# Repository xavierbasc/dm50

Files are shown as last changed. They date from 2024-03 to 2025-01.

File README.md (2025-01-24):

# DM50 calculator

The main features of the calculator are the following:

 - 32bit ARM Cortex-M33 MCU ultra low power.
 - Mathematical coprocessor acceleration.
 - Floating Point Unit (FPU).
 - 2MB RAM (STM32U595RJ).
 - 4MB FLASH memory (STM32U595RJ).
 - 16MB FLASH storage Octo-SPI (accessible via USB).
 - USBC port, connects as USB mass storage device.
 - Serial port for communications with external devices.
 - MicroSD memory slot.
 - Integrated speaker and stereo audio output (jack 3.5).
 - Graphic LCD Display (128x64 dots).
 - ESD protection of USBC.
 - LiPO 3.7V rechargeable battery, with JST PH2.0 connector.
 - Possibility of using AAA batteries.
 - Battery charge level sensor.
 - USB power and battery charging status LED indicators.
 - JTAG debug port.
 - Temperature sensor.
 - Same number of keys as the legendary HP48.

# Hardware
Below is a list of the most relevant electronic components:

1. Processor: STM32U5 ARM Cortex-M33 ultra low power with FPU.
2. Display: EA_DOGL128L-6 STN reflective display 128x64.
3. Flash memory: W25Q128JVSIQ 16MB Flash.
4. Voltage regulator: ADP2108 Vin 2.3 - 5.5, Vout 3.3.
5. USB protection: USBLC6-2 ESD protection of VBUS.
6. Battery charger: MCP73831 Lithium-Ion/Lithium-Polymer Battery Charger.

Some of the supported batteries are as follows:

| Batteries | Capacity (mha) |
| --- | :---: |
| AAA Alkaline | 900 - 1155 |
| AAA Ni-MH | 800 - 1000 |
| LiPO 402025 (4.0x20x25) | 150 |
| LiPO LP272247 (2.7x22x47) | 260 |

***Electronic design***:
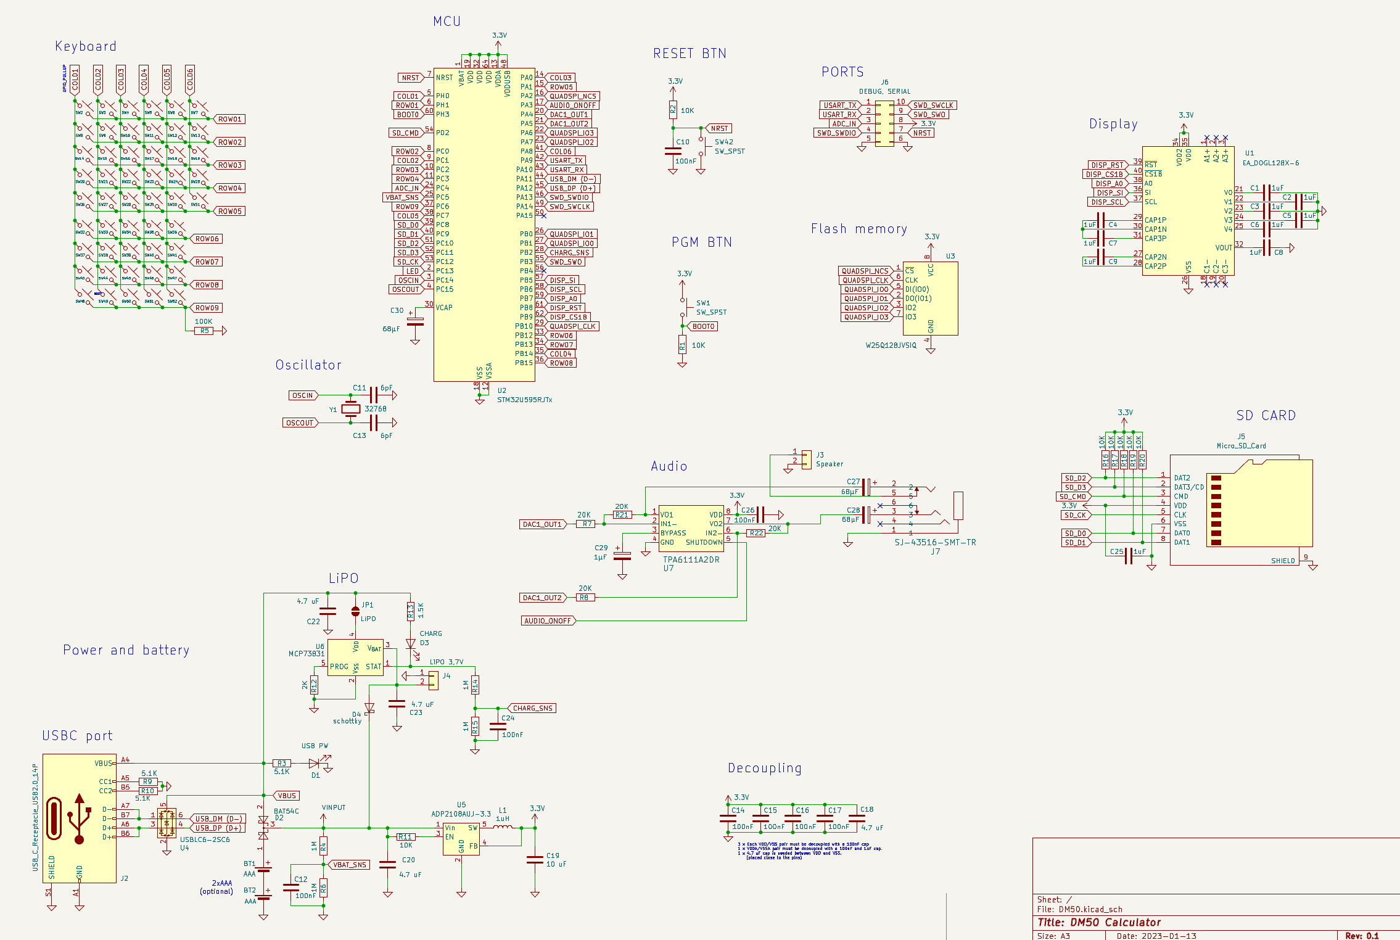
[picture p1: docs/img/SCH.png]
New Sch New Schema


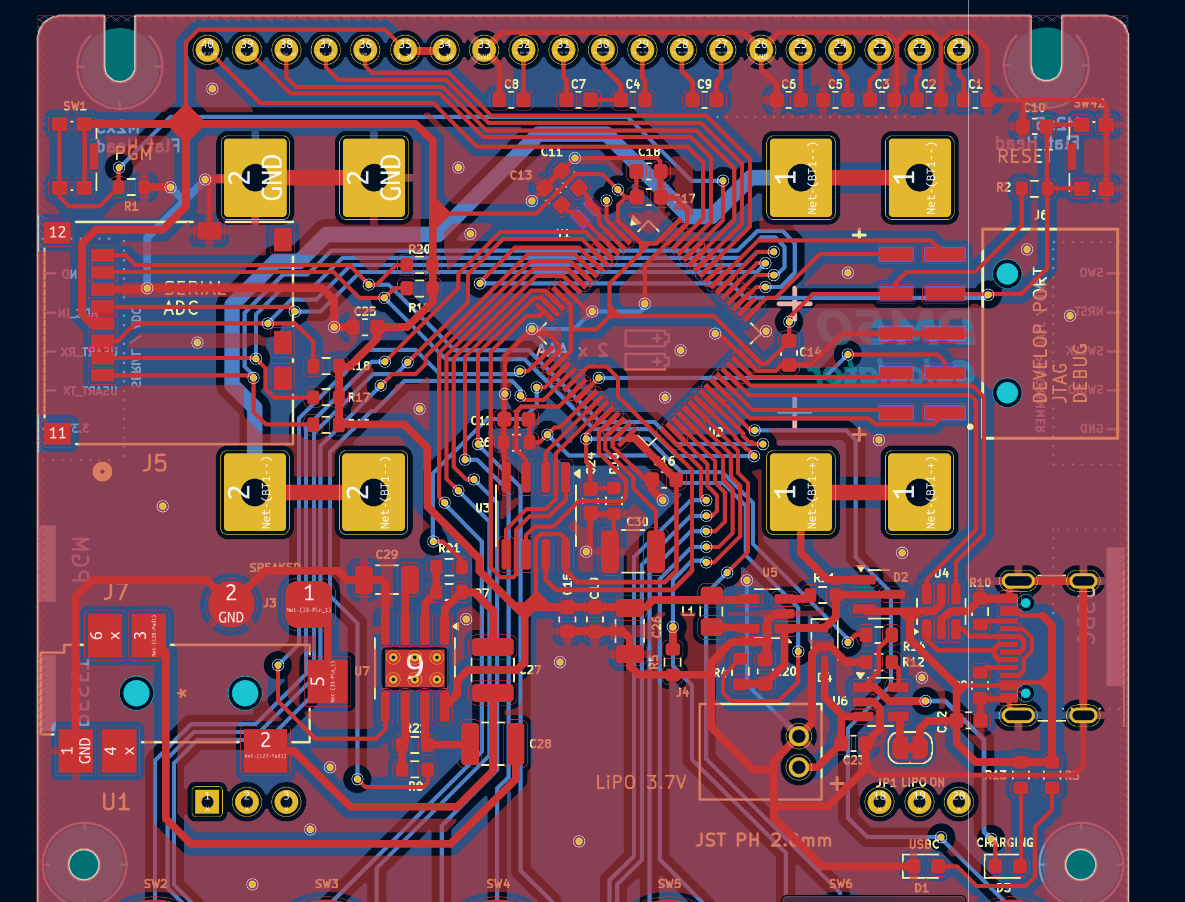
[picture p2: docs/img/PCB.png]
PCB PCB EDA


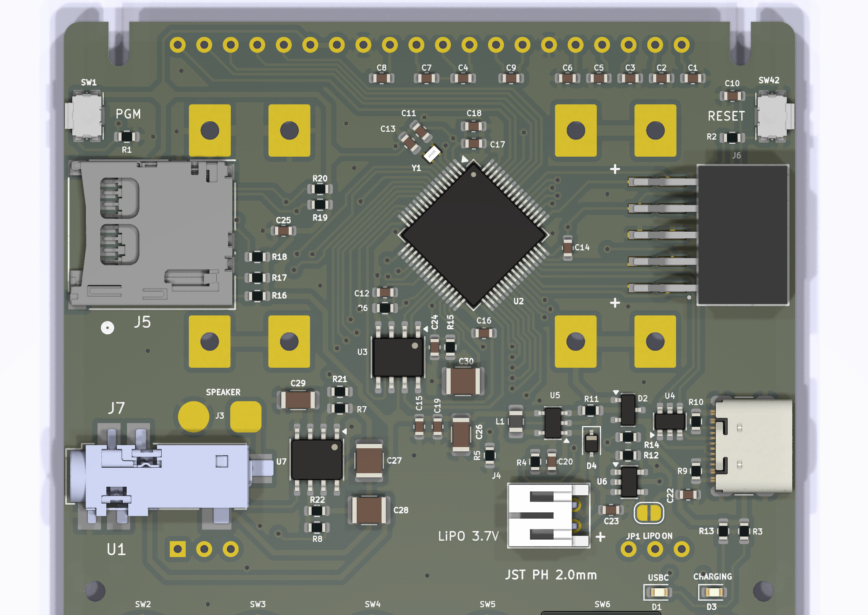
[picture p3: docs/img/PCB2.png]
PCB render


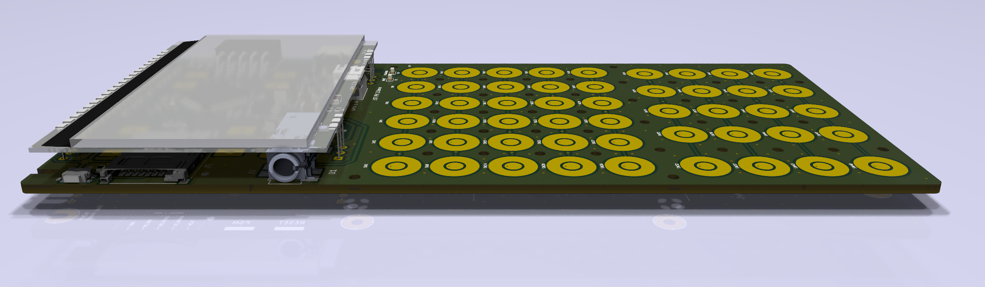
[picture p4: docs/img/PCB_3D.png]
PCB front


## Case
Freecad software has been used to design the casing.
The spaces have been optimized to reduce the size, continuously giving shape to the calculator and improving the user experience.
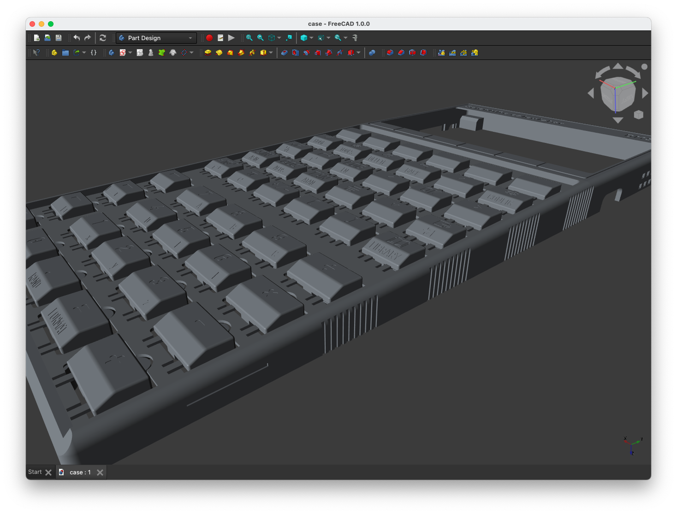
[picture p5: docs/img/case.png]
CASE


## Faceplate
A master faceplate has been designed although it can be exchanged by the user through a simple manual process.

The front plate is printed on photographic paper and cut to size, with professional results. A photo-quality printer is recommended, such as the Epson Ecotank.

To create the faceplate, the Inkscape tool has been used to edit the SVG and the font used is Latin Modern Math, licensed by the GUST Font License, developed by the TeX user group in Poland, and can be used for academic use. , commercial or academic.

[Latin Modern Math font](https://www.gust.org.pl/projects/e-foundry/latin-modern "Latin Modern Math font")

# Software
TBD

# Reference
Comparison of the ***hardware*** used in the different reference calculators:

| Year | Model | Processor | FREQ | RAM | FLASH | Display | MIPS |
| :-: | - | - | -: | -: | -: | :-: | -: |
| 1988 | [HP42S](https://en.wikipedia.org/wiki/HP-42S) | HP Saturn (1LF5) | - | 8KB | 64KB | 131×16 | 0.5 |
| 1993 | [HP48G](https://en.wikipedia.org/wiki/HP_48_series) | HP Saturn (1LF2) | 4MHz | 32KB | 512KB | 131×64 | 0.5 |
| 2006 | [HP50G](https://en.wikipedia.org/wiki/HP_49/50_series) | ARM9 S3C2410 | 75MHz | 512KB | 2MB | 131×80 | 75 |
| 2013 | [TI-Nspire CX II](https://en.wikipedia.org/wiki/TI-Nspire_series#TI-Nspire_CX_II_and_TI-Nspire_CX_II_CAS) | TI OMAP 3530 | 396MHz | 64MB | 128MB | 320x240 | 792 |
| 2016 | [NumWorks](https://www.numworks.com/resources/engineering/hardware/) | STM32F730V8T6 | 216MHz | 256KB | 6MB | 320x240 | 432 |
| 2017 | [DM42](https://www.swissmicros.com/product/dm42) | STM32L476RG | 80MHz | 128KB | 6MB | 400×240 |  100 |
| 2019 | [HP Prime G2](https://en.wikipedia.org/wiki/HP_Prime) | i. MX 6ULL | 528MHz | 256MB | 512MB | 320×240 | 1710 |
| 2021 | [OpenRPNCalc](https://github.com/apoluekt/OpenRPNCalc) | STM32L476 | 8MHz | 128KB | 1MB | 400x240 | 100 |
| 2023 | [DM32](https://www.swissmicros.com/product/dm42) | STM32U575 | 160MHz | 786KB | 1MB | 400×240 |  240 |
| 2024 | [`DM50`](https://github.com/xavierbasc/dm50-calculator) | STM32U595RJ | 160MHz | 2MB | 20MB | 128×64 | 240 |

List of ***software*** used as firmware in some calculators:

1. [DB48X](https://48calc.org/): DB48X is a modern implementation of RPL.
2. [C47](https://47calc.com/): C47 is a RPN Scientific Calculator (old WP43C project).
3. [WP43](https://gitlab.com/rpncalculators/wp43): Firmware for the WP43 pocket calculator (old WP43S project).
4. [Free42](https://github.com/thomasokken/free42): Free42 is a software clone of the Hewlett-Packard 42S calculator.
5. [TCalc](https://github.com/tylertian123/TCalc): Firmware for STM32 CAS calculator.
6. [TinyExpr](https://github.com/codeplea/tinyexpr): parser and evaluation for math expressions.
7. [Giac](https://www-fourier.ujf-grenoble.fr/~parisse/giac.html): CAS calculation engine used in HP Prime, Casio Graph 90, Casio 35eii, TI Nspire CX, Numworks, and software such as Geogebra and PocketCAS.

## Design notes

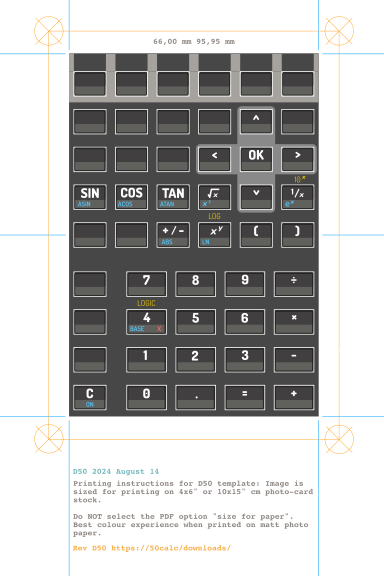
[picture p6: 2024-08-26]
docs/bezel/DM50_BEZEL01.png

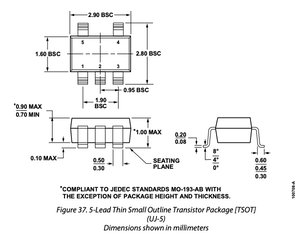
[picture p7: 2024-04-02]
docs/img/ADP2108AUJ-3.3.png

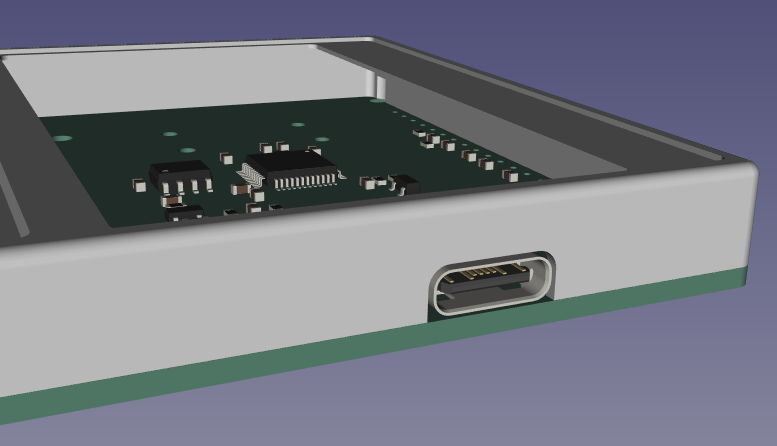
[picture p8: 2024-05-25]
docs/img/usbc.png

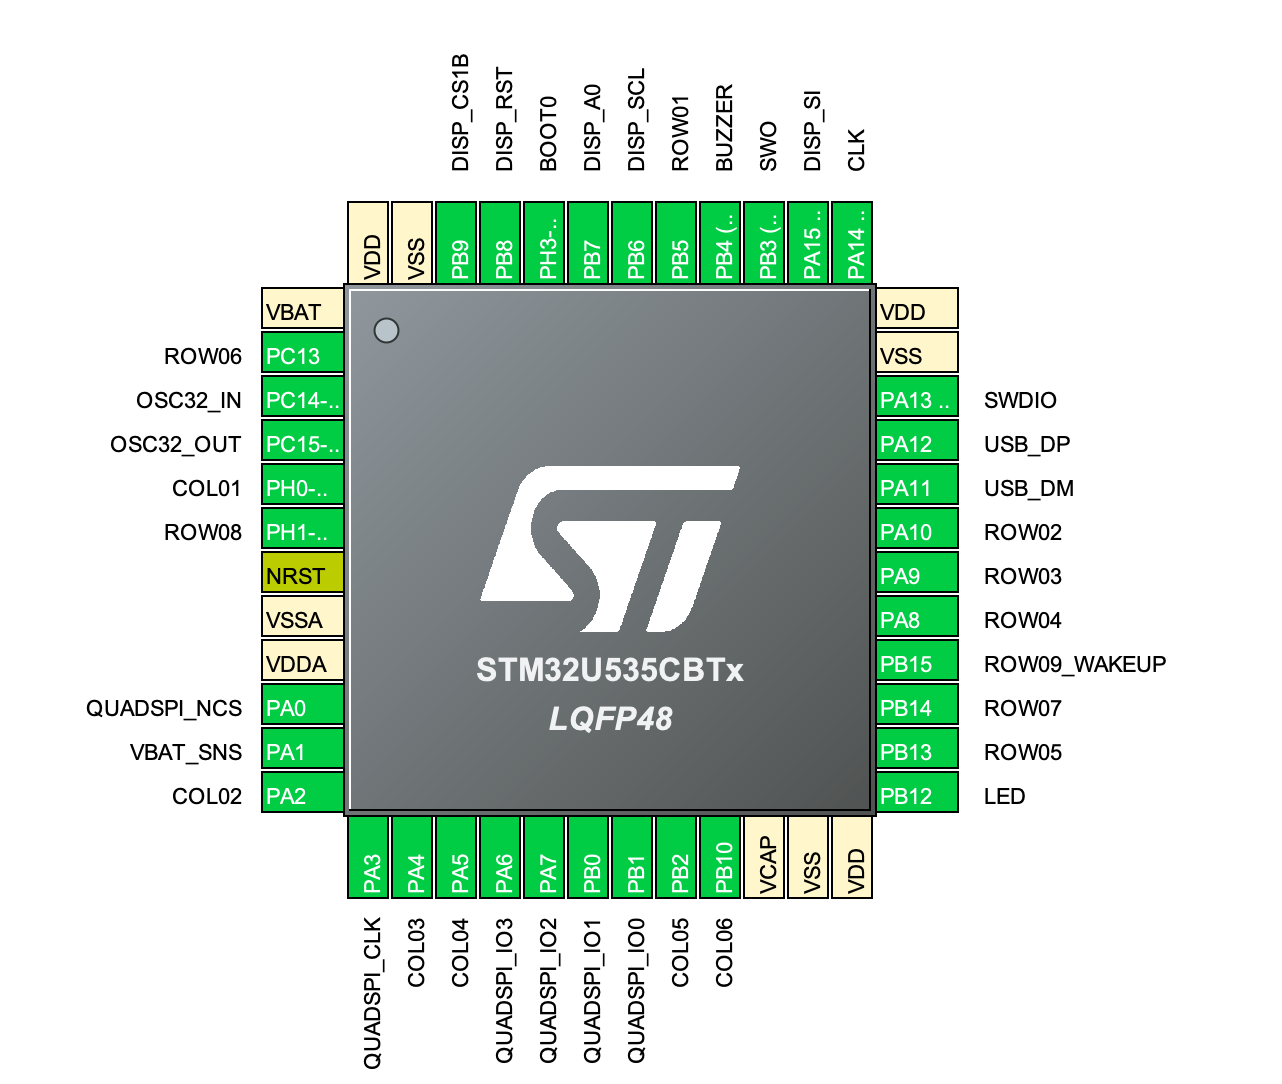
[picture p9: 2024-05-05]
docs/img/MCU.png

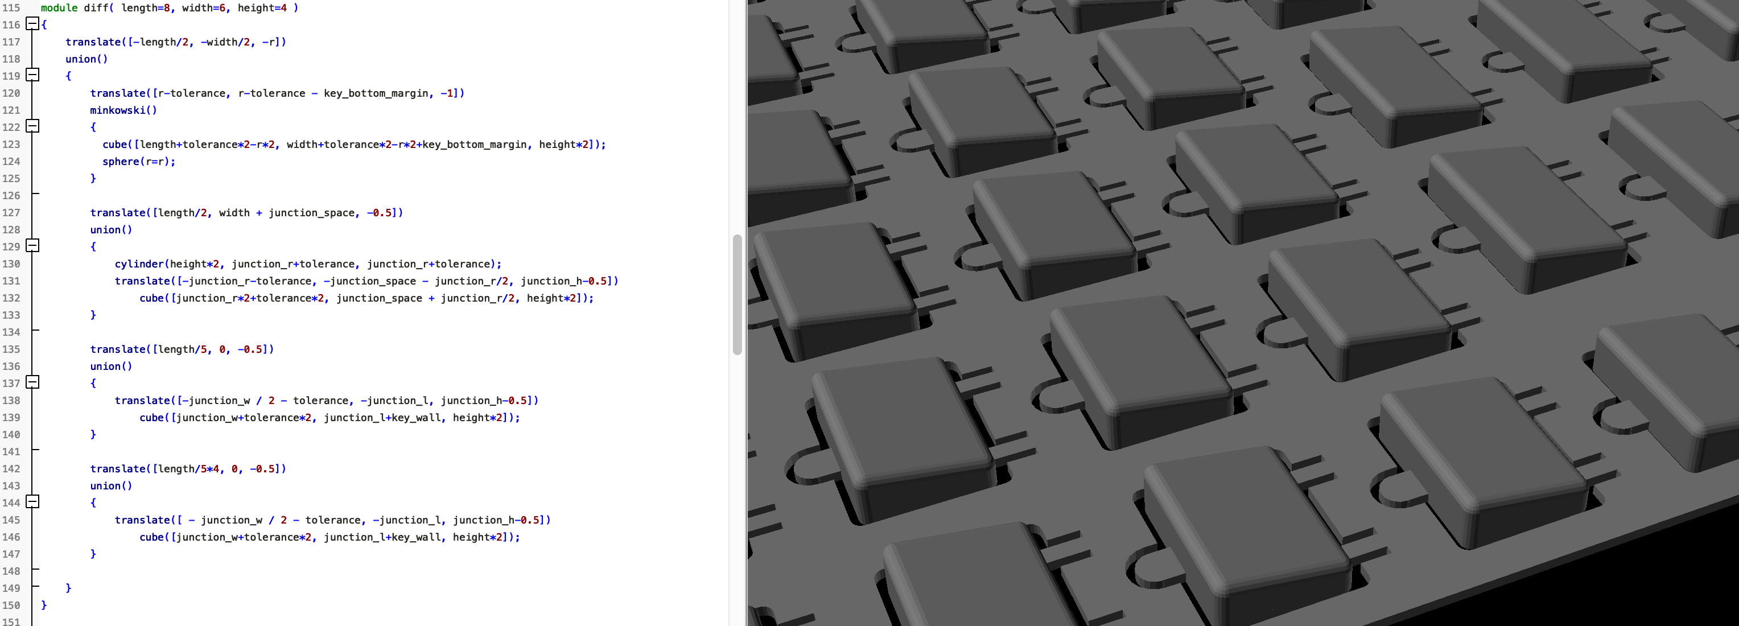
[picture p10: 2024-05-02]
docs/img/keyboard.png

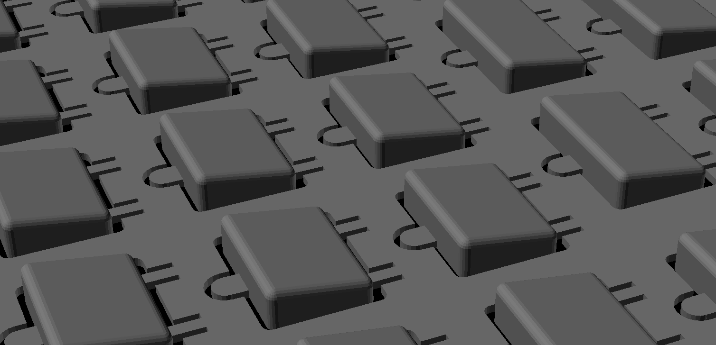
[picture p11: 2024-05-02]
docs/img/keyboard_f.png

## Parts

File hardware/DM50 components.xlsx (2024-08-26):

Reference | Value | Datasheet | Footprint | Qty | Digikey | Package | Price € | TOTAL | Function |  | BASIC (AAA) | PRO (LiPO+microSD)
C1,C2,C3,C4,C5,C6,C7,C8,C9,C25 | 1uF | https://www.digikey.es/en/products/detail/yageo/CC0603KRX7R7BB105/2833611 | Capacitor_SMD:C_0603_1608Metric | 10 | CC0603KRX7R7BB105 | 0603 | 0.09 | 0.9 | Core | UNION 1uF (A8) | 0.9 | 0.9
C10,C12,C14,C15,C16,C17,C24,C26 | 100nF | https://www.digikey.es/es/products/detail/yageo/CC0603KRX7R7BB104/302822 | Capacitor_SMD:C_0603_1608Metric | 8 | CC0603KRX7R7BB104 | 0603 | 0.09 | 0.72 | Core |  | 0.72 | 0.72
C11,C13 | 6pF | https://www.digikey.es/es/products/detail/samsung-electro-mechanics/CL10C060DB8NNNC/3887792 | Capacitor_SMD:C_0603_1608Metric | 2 | CL10C060DB8NNNC | 0603 | 0.09 | 0.18 | Core |  | 0.18 | 0.18
C18,C20,C22,C23 | 4.7 uF | https://www.digikey.es/es/products/detail/samsung-electro-mechanics/CL10A475KP8NNNC/3886702 | Capacitor_SMD:C_0603_1608Metric | 4 | CL10A475KP8NNNC | 0603 | 0.09 | 0.36 | Core |  | 0.36 | 0.36
C19 | 10 uF | https://www.digikey.es/es/products/detail/taiyo-yuden/LMK107BBJ106MALT/3662195 | Capacitor_SMD:C_0603_1608Metric | 1 | LMK107BBJ106MALT | 0603 | 0.14 | 0.14 | Core |  | 0.14 | 0.14
C27,C28,C30 | 68µF | https://www.digikey.es/es/products/detail/tdk-corporation/C3216X5R0J686M160AB/3951907 |  | 3 | C3216X5R0J686M160AB | 1206 | 0.49 | 1.47 | AUDIO (2/3) | MODIFICADO | 0.49 | 1.47
C29 | 1µF | https://www.digikey.es/es/products/detail/yageo/CC0603KRX7R7BB105/2833611 | Capacitor_SMD:C_1206_3216Metric | 1 | CC0603KRX7R7BB105 | 0603 | 0.09 | 0.09 | Core |  | 0.09 | 0.09
D1 | GREEN LED | https://www.digikey.es/es/products/detail/liteon/LTST-C190GKT/269230 | LED_SMD:LED_0603_1608Metric | 1 | LTST-C190GKT | 0603 | 0.19 | 0.19 | Core |  |  | 0.19
D2 | BAT54C | https://www.digikey.es/es/products/detail/evvo/BAT54C/21407177 | Package_TO_SOT_SMD:SOT-23 | 1 | BAT54C | SOT-23 | 0.1 | 0.1 | Core |  | 0.1 | 0.1
D3 | RED LED | https://www.digikey.es/es/products/detail/liteon/LTST-S270KRKT/386895 | LED_SMD:LED_0603_1608Metric | 1 | LTST-S270KRKT | 0603 | 0.19 | 0.19 | Core |  | 0.19 | 0.19
D4 | schottky | https://www.digikey.es/es/products/detail/nexperia-usa-inc/1PS76SB10-115/1127159 | Diode_SMD:D_SOD-323 | 1 | 1PS76SB10,115 | SOD-323 | 0.17 | 0.17 | Core |  |  | 0.17
J2 | USB_C_Receptacle_USB2.0_14P | https://www.digikey.es/es/products/detail/amphenol-cs-commercial-products/12402012E212A/13683192 | Connector_USB:USB_C_Receptacle_GCT_USB4105-xx-A_16P_TopMnt_Horizontal | 1 | 12402012E212A | USBC 24p | 0.76 | 0.76 | Core |  | 0.76 | 0.76
J3 | Speaker | https://www.digikey.es/es/products/detail/cui-devices/CMS-15113-078L100/8581916 | DM50:Buzzer | 1 | CMS-15113-078L100 | 15x11x3 mm | 1.39 | 1.39 | AUDIO |  |  | 1.39
J4 | LiPO 3,7V | https://www.digikey.es/es/products/detail/jst-sales-america-inc/S2B-PH-K-S/926626 | DM50:CONN_S2B-PH-K-S_JST | 1 | S2B-PH-K-S | S2B-PH-K | 0.11 | 0.11 | LIPO |  |  | 0.11
J5 | Micro_SD_Card | https://www.digikey.es/es/products/detail/gct/MEM2075-00-140-01-A/9859614 |  | 1 | MEM2075-00-140-01-A | MEM2075 | 1.78 | 1.78 | MICROSD | MODIFICADO |  | 1.78
J6 | DEBUG, SERIAL | https://www.digikey.es/es/products/detail/w%C3%BCrth-elektronik/610110249221/5047732 | DM50:610110249221 | 1 | 610110249221 | CONN 2x10 | 1.94 | 1.94 | DEBUG-SERIAL | MODIFICADO |  | 1.94
J7 | SJ-43516-SMT-TR | https://www.digikey.es/es/products/detail/cui-devices/SJ-43516-SMT-TR/669721 | DM50:SJ-43516-SMT_CUD | 1 | SJ-43516-SMT-TR | CONN JACK 3.5 | 0.94 | 0.94 | AUDIO |  |  | 0.94
L1 | 1uH | https://www.digikey.es/es/products/detail/tdk-corporation/MLZ1608A1R0WT000/2465143 | Inductor_SMD:L_0805_2012Metric_Pad1.15x1.40mm_HandSolder | 1 | MLZ1608A1R0WT000 | 0603 | 0.13 | 0.13 | Core |  | 0.13 | 0.13
R1,R2,R11,R16,R17,R18,R19,R20 | 10K | https://www.digikey.es/es/products/detail/stackpole-electronics-inc/RMCF0603JT10K0/1758104 | Resistor_SMD:R_0603_1608Metric | 8 | RMCF0603JT10K0 | 0603 | 0.09 | 0.72 | Core |  | 0.72 | 0.72
R3,R9,R10 | 5.1K | https://www.digikey.es/es/products/detail/yageo/RC0603FR-075K1L/727268 | Resistor_SMD:R_0603_1608Metric | 3 | RC0603FR-075K1L | 0603 | 0.09 | 0.27 | Core |  | 0.27 | 0.27
R4,R6,R14,R15 | 1M | https://www.digikey.es/es/products/detail/stackpole-electronics-inc/RMCF0603FT1M00/1761036 | Resistor_SMD:R_0603_1608Metric | 4 | RMCF0603FT1M00 | 0603 | 0.09 | 0.36 | Core |  | 0.36 | 0.36
R5 | 100K | https://www.digikey.es/es/products/detail/yageo/RC0603FR-07100KL/726889 | Resistor_SMD:R_0603_1608Metric | 1 | RC0603FR-07100KL | 0603 | 0.09 | 0.09 | Core |  | 0.09 | 0.09
R7,R8,R21,R22 | 20K | https://www.digikey.es/es/products/detail/stackpole-electronics-inc/RMCF0603JT10K0/1758104 | Resistor_SMD:R_0603_1608Metric | 4 | RMCF0603JT10K0 | 0603 | 0.09 | 0.36 | Core |  | 0.36 | 0.36
R12 | 2K | https://www.digikey.es/es/products/detail/panasonic-electronic-components/ERJ-3EKF2001V/196183 | Resistor_SMD:R_0603_1608Metric | 1 | ERJ-3EKF2001V | 0603 | 0.09 | 0.09 | Core |  | 0.09 | 0.09
R13 | 1.5K | https://www.digikey.es/es/products/detail/yageo/RC0603JR-071K5L/726689 | Resistor_SMD:R_0603_1608Metric | 1 | RC0603JR-071K5L | 0603 | 0.09 | 0.09 | Core |  | 0.09 | 0.09
SW1,SW42 | SW_SPST | https://www.digikey.es/es/products/detail/c-k/PTS526-SK15-SMTR2-LFS/10056626 | Button_Switch_SMD:SW_SPST_CK_KMS2xxG | 2 | KMS223GPLFG | KMS223 | 0.61 | 1.22 | Core |  | 1.22 | 1.22
SW2,SW3,SW4,SW5,SW6,SW7,SW8,SW9,SW10,SW11,SW12,SW13,SW14,SW15,SW16,SW17,SW18,SW19,SW20,SW21,SW22,SW23,SW24,SW25,SW26,SW27,SW28,SW29,SW30,SW31,SW32,SW33,SW34,SW35,SW36,SW37,SW38,SW39,SW40,SW41,SW43,SW44,SW45,SW46,SW47,SW48,SW49,SW50,SW51,SW52 | BT_SMD | https://es.aliexpress.com/item/1005001444483167.html?srcSns=sns_Copy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 | DM50:dm50-button | 50 |  | dome 7.0mm, three dimple | 0.02 | 1 | Core |  | 1 | 1
U1 | EA_DOGL128X-6 | https://www.digikey.es/es/products/detail/display-visions/EA-DOGL128L-6/4896695 | DM50:EA_DOGL128-6 | 1 | EA DOGL128L-6 | EA DOGL128L-6 | 11.22 | 11.22 | Core |  | 11.22 | 11.22
U2 | STM32U595RJTx | https://www.st.com/resource/en/datasheet/stm32u595rj.pdf | Package_QFP:LQFP-64_10x10mm_P0.5mm | 1 | STM32U595RJTx | LQFP64 | 13.7 | 13.7 | Core |  | 13.7 | 13.7
U3 | W25Q128JVSIQ | https://www.digikey.es/es/products/detail/winbond-electronics/W25Q128JVSIQ/5803943 | Package_SO:SOIC-8_3.9x4.9mm_P1.27mm | 1 | W25Q128JVSIQ | 8-SOIC | 1.55 | 1.55 | Core |  | 1.55 | 1.55
U4 | USBLC6-2SC6 | https://www.digikey.es/es/products/detail/stmicroelectronics/USBLC6-2SC6/1040559 | Package_TO_SOT_SMD:SOT-23-6 | 1 | USBLC6-2SC6 | SOT-23-6 | 0.31 | 0.31 | Core |  | 0.31 | 0.31
U5 | ADP2108AUJ-3.3 | https://www.digikey.es/es/products/detail/analog-devices-inc/ADP2108AUJZ-3-3-R7/2042669 | Package_TO_SOT_SMD:TSOT-23-5 | 1 | ADP2108AUJZ-3.3-R7 | TSOT-23-5 | 3.13 | 3.13 | Core | MODIFICAR | 3.13 | 3.13
U6 | MCP73831 | https://www.digikey.es/es/products/detail/microchip-technology/MCP73831T-2ACI-OT/964301 | Package_TO_SOT_SMD:SOT-23-5 | 1 | MCP73831T-2ACI/OT | SOT-23-5 | 0.68 | 0.68 | LIPO |  |  | 0.68
U7 | TPA6111A2DR | https://www.digikey.es/es/products/detail/texas-instruments/TPA6111A2DR/382220 | Package_SO:SOIC-8-1EP_3.9x4.9mm_P1.27mm_EP2.41x3.81mm_ThermalVias | 1 | TPA6111A2DR | 8-SOIC | 0.76 | 0.76 | AUDIO |  |  | 0.76
Y1 | 32768 | https://www.digikey.es/es/products/detail/abracon-llc/ABS05-32-768KHZ-9-T/3508064 | DM50:XTAL_ABS05-32.768KHZ-9-T | 1 | ABS05-32.768KHZ-9-T | 1.6x1.0 | 0.78 | 0.78 | Core |  | 0.78 | 0.78
CONN AAA | CONN AAA | https://www.digikey.es/es/products/detail/mpd-memory-protection-devices/BK-82/2079903 |  | 4 | BK-82 |  | 0.4 | 1.6 | AAA |  | 1.6
 |  |  |  |  |  |  |  |  |  |  |  | 0
PCB jlcpcb |  | https://jlcpcb.com | 33€ / 5 PCBs + SMT Stencil + shipping | 1 |  |  | 7 | 7 | PCB |  | 7 | 7
RESIN CASE |  | https://www.elegoo.com/products/abs-like-photopolymer-resin-v3 | 20€ / 1kg | 1 |  |  | 6 | 6 | CASE |  | 6 | 6
Screws |  | https://a.aliexpress.com/_EHVNaDX | 2€ / 100 pieces | 6 |  | M2 x 4mm | 0.02 | 0.12 |  |  | 0.12 | 0.12
Nuts |  | https://a.aliexpress.com/_EyaJlxR | 3€ / 50 pieces | 6 |  | M2 x 3mm | 0.06 | 0.36 |  |  | 0.36 | 0.36
LiPO |  | https://a.aliexpress.com/_Ez9zchP | 402025, 3,7 V, 150mAh | 1 |  | 20x25 | 4 | 4 | LIPO |  |  | 4
 |  |  |  |  |  |  |  | 47.89 | ELECTRONIC |  | 38.95 | 47.89
Superfluous not accounted: |  |  |  |  |  |  |  | 75.4269 | TOTAL +IVA |  | 60.6095 | 75.4269
Adhesive paper for domes
Acrylic paints (Vallejo, etc)
Acrylic grip mix on plastics
Black EVA foam
Photo paper for bezel
CAMBIOS PROPUESTOS:
U6 | MCP1603T-330I/OS | https://www.digikey.es/es/products/detail/microchip-technology/MCP1603T-330I-OS/1098431 |  | 1 |  | TSOT-23-5 | 1.19 | 1.19

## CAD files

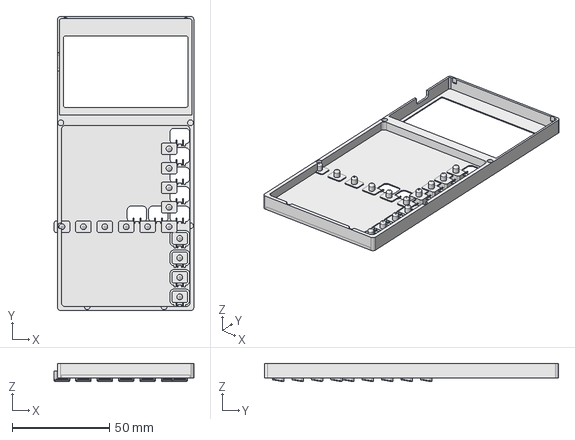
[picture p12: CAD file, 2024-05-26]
3d/case.FCStd
71.7 x 151.0 x 9.40 mm

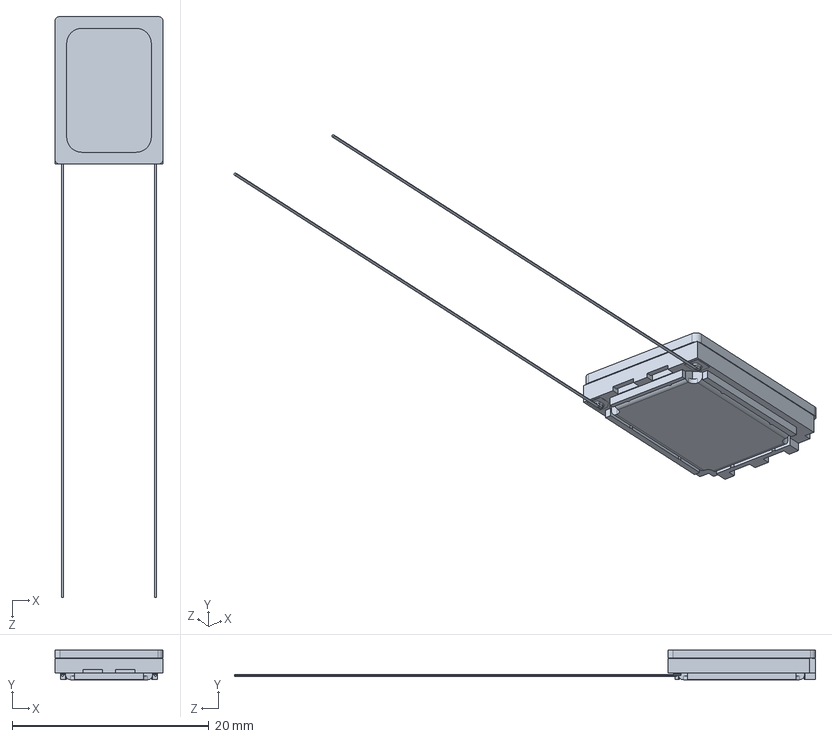
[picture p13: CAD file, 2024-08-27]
hardware/step/CUI_DEVICES_CMS-15113-078L100.step
11.0 x 3.00 x 59.1 mm

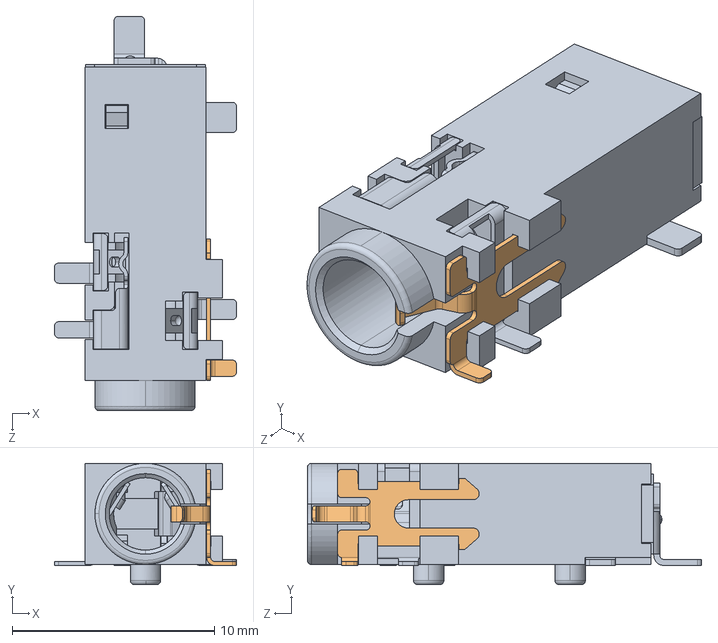
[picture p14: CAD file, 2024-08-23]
hardware/step/CUI_DEVICES_SJ-43516-SMT-TR.step
9.00 x 6.00 x 19.5 mm

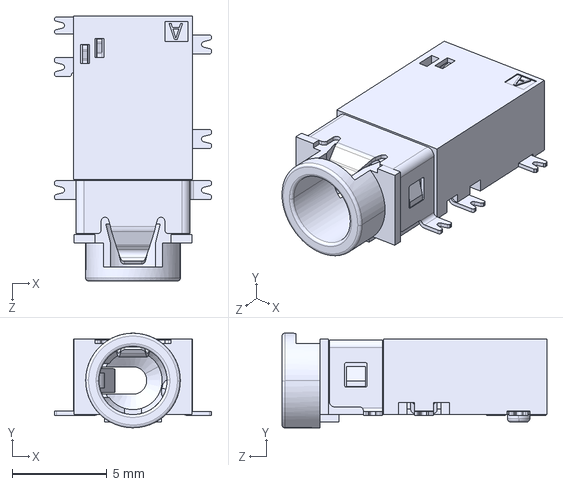
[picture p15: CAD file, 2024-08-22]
hardware/step/CUI_DEVICES_SJ2-35954D-SMT-TR.step
8.30 x 5.00 x 14.0 mm

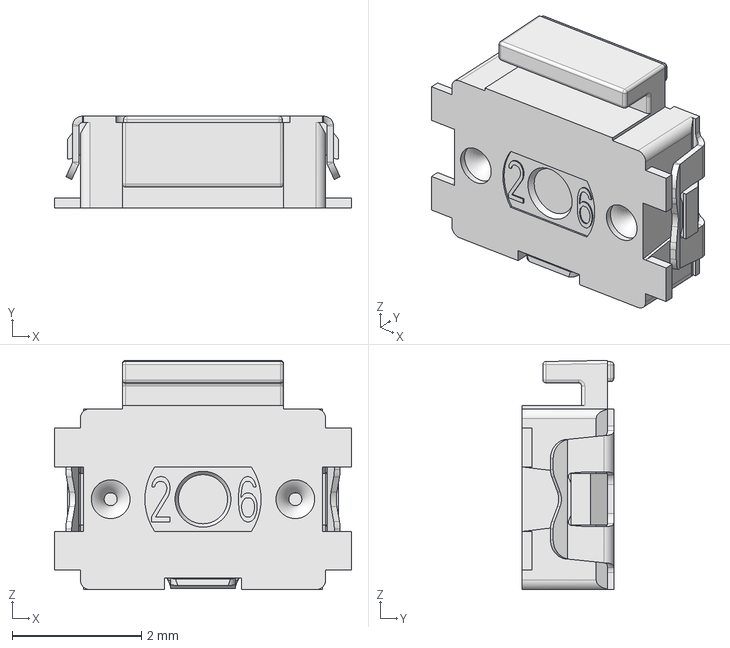
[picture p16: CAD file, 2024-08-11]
hardware/step/KMS223GPLFG.step
4.60 x 1.42 x 3.55 mm

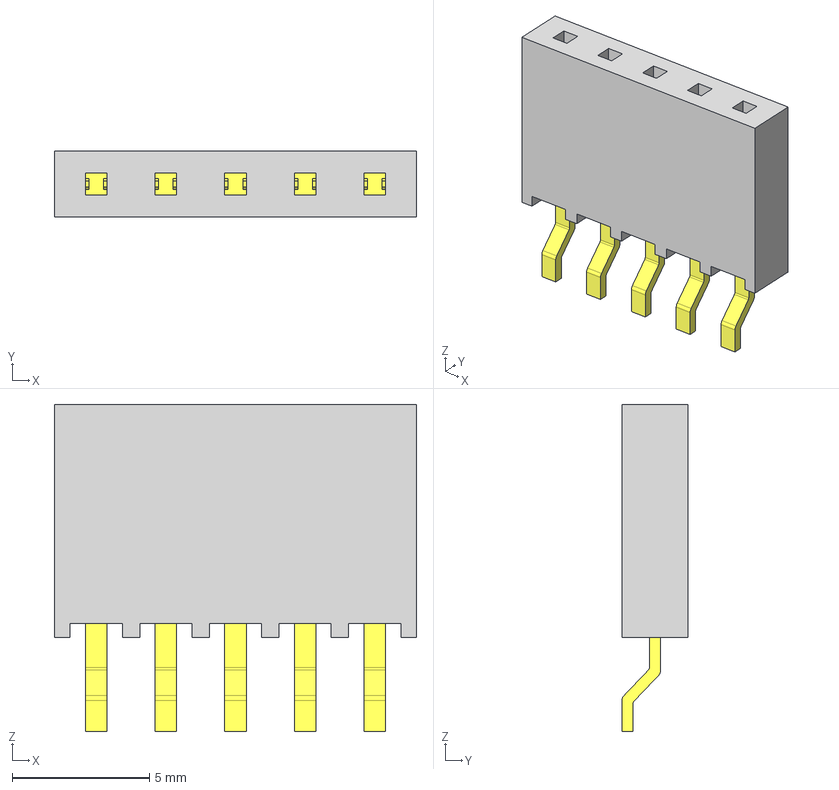
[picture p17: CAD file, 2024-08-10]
hardware/step/SAMTEC-SMH-105-02-X-S.step
13.2 x 2.41 x 11.9 mm
SMH-105-S_socket
C-08-03-05-S_SMH

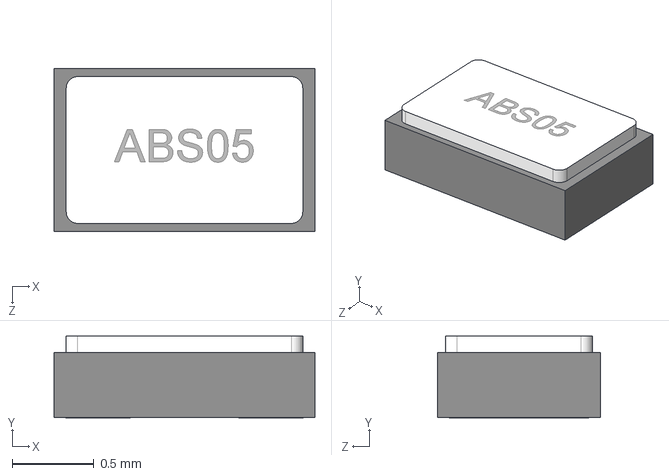
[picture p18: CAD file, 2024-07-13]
hardware/step/ABS05-32.768KHZ-9-T.step
1.60 x 0.503 x 1.00 mm

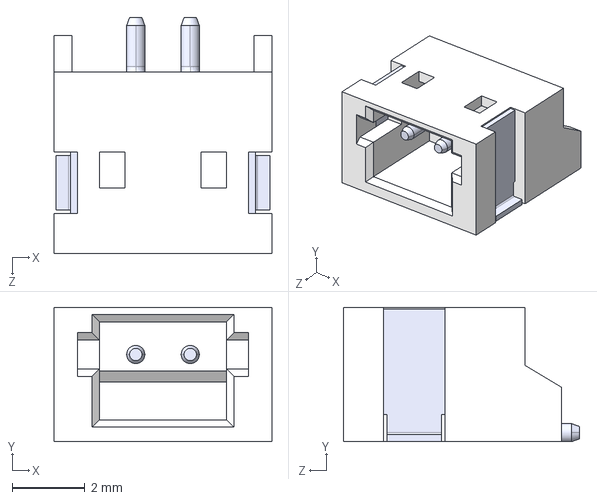
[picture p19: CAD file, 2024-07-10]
hardware/step/S2B-ZR-SM4A-TF.step
6.00 x 3.70 x 6.50 mm

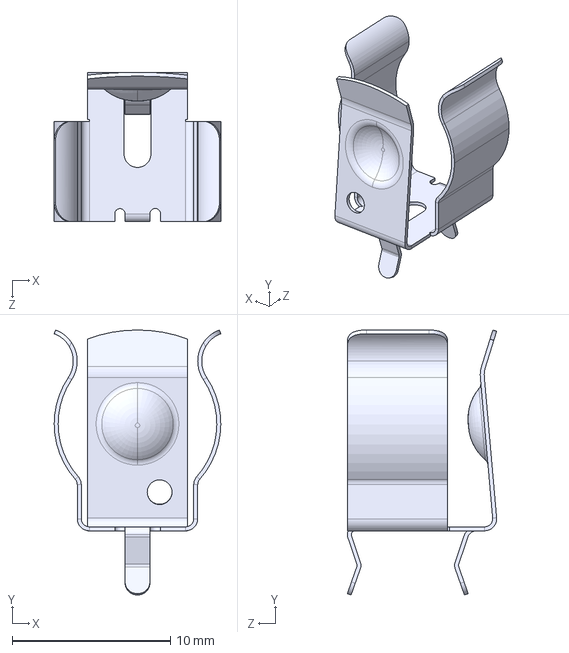
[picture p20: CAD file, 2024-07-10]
hardware/step/BK-82.step
10.5 x 16.8 x 9.45 mm

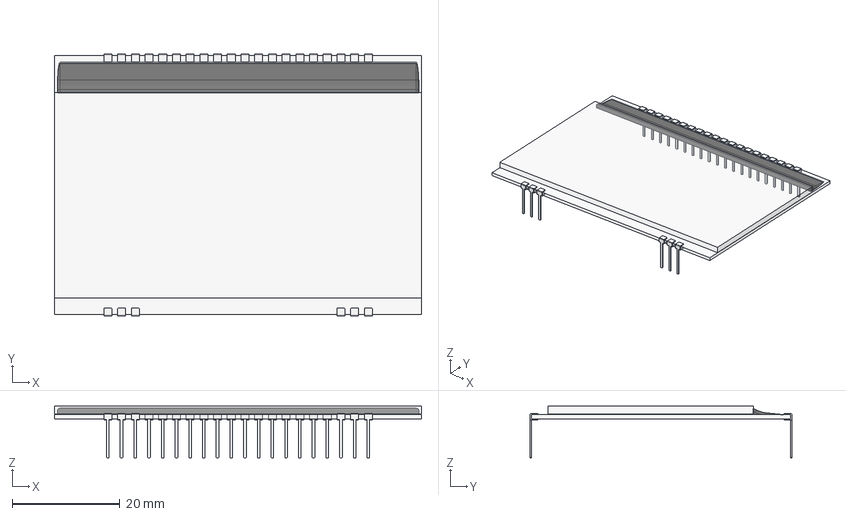
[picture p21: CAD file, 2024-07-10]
hardware/step/EA DOGL128.step
68.0 x 48.5 x 9.58 mm
dogpin x 26

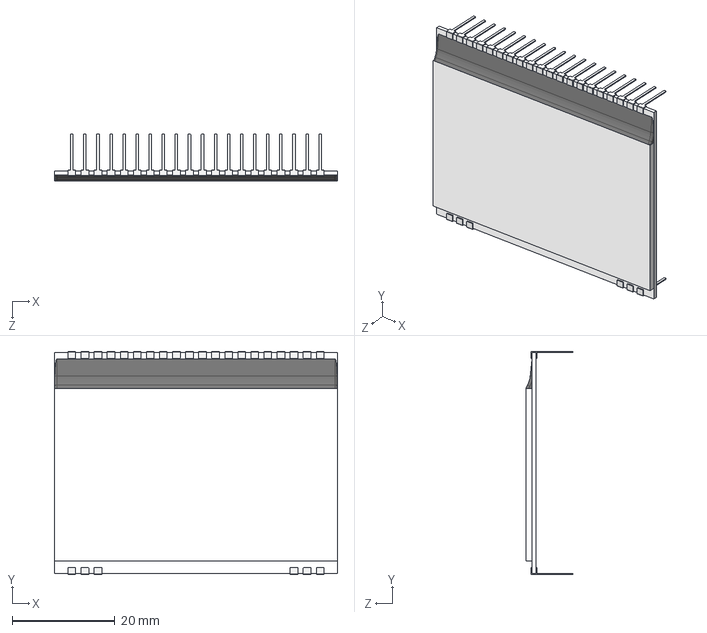
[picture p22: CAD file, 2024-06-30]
hardware/step/EA DOGM128.STEP
55.0 x 43.4 x 9.20 mm
EA-DOGM128-SCREEN
dogpin x 26

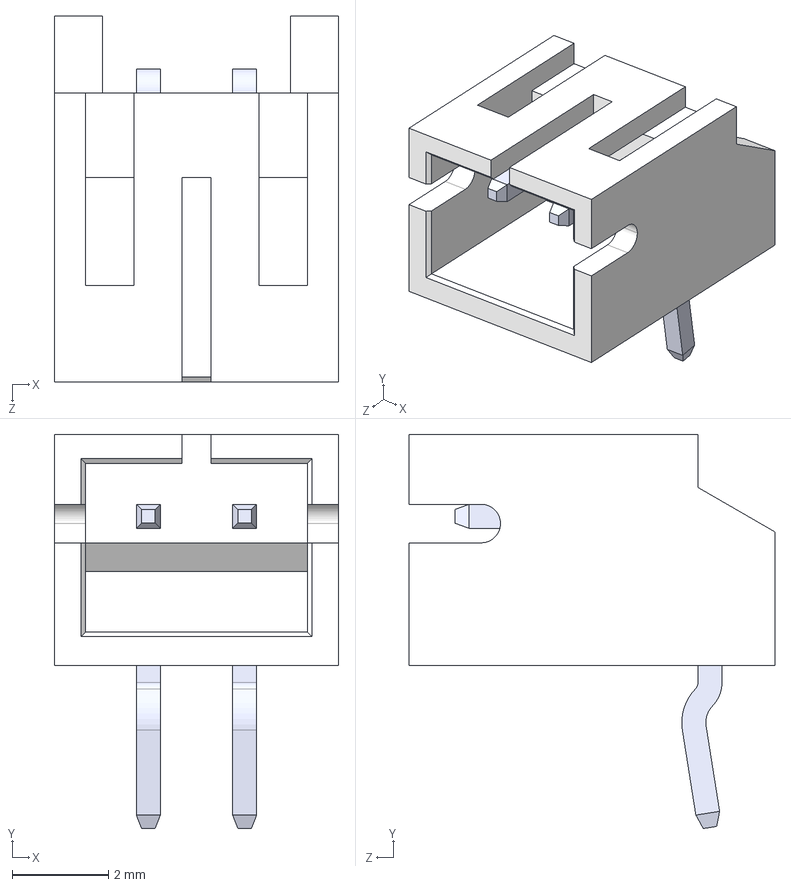
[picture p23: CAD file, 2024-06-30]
hardware/step/S2B-PH-K-S.STEP
5.90 x 8.18 x 7.60 mm

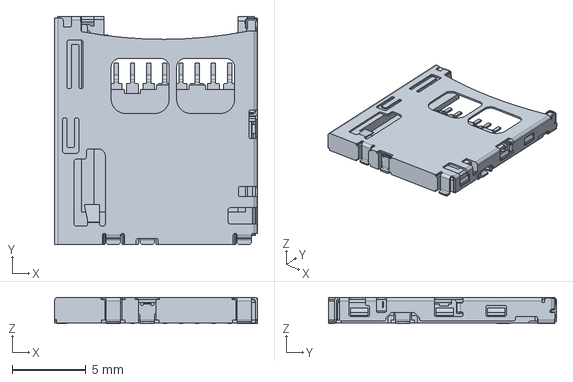
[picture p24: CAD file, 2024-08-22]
hardware/step/5025700893.step
13.8 x 15.5 x 1.80 mm

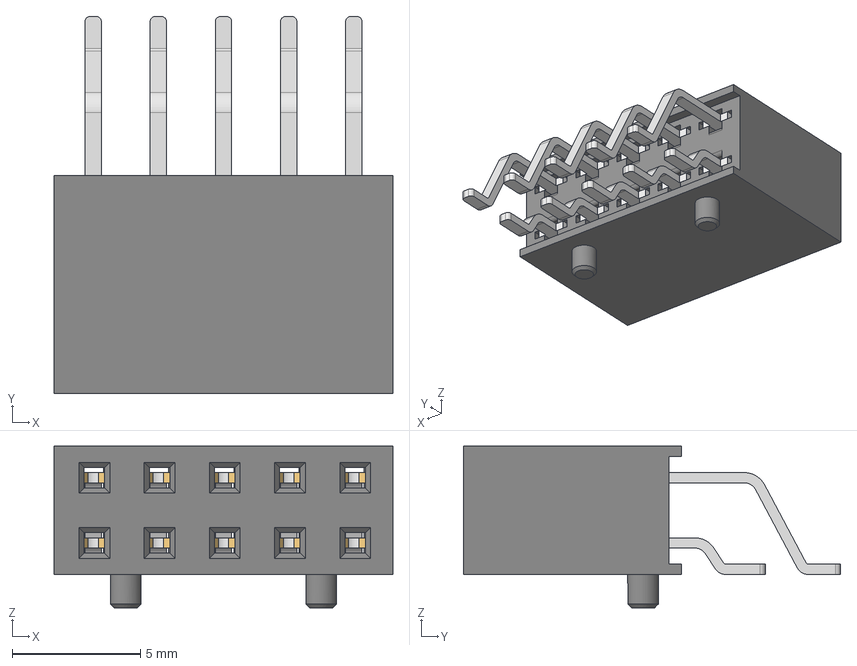
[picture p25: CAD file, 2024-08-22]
hardware/step/610110249221_Download_STP_610110249221_rev1.step
13.2 x 14.7 x 6.30 mm
6103xx249221_PIN COURTE x 5
6103xx249221_PIN LONGUE x 5

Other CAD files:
hardware/step/EA DOGL128.FCStd

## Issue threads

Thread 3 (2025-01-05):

Screen size is insufficient for HP50G or DB48x/DB50x

c3d, 2025-01-05:
Hi @xavierbasc, great initiative! I look forward to having a cheap, custom, open-source platform to run DB50x on ;-)

On the front-page, you list two things that make your intent a little bit unclear:

* Graphic LCD Display (128x64 dots).
* A list of software used in calculators that includes DB48x, C47 or WP43

This makes the goal of your hardware project a little unclear. If you want to run the original HP ROMs through some kind of Saturn emulator, in the same vein as the HP50G did, then the resolution is close, but insufficient. The HP48 did indeed have 64 pixels vertically, but it was 131 horizontally (don't ask). So 128 means you lose 3 pixels. The HP50G, on the other hand, had 80 pixels vertically, so this makes things even worse. Finally, the SwissMicros devices settled for a high-contrast black and white 400x240 pixel screen.

There is a [variety of displays available on the market](https://www.panelook.com/bramodlist.php?brands[]=115&resolution_pixels=18750). Have you already settled specifically on this 128x64 for any particular reason, or is this something that could be more open in the design?

Here are some options I can think of:

1. High-resolution e-ink like SwissMicros. Pros: porting the existing firmware is easy. Cons: Not direct multiples of the HP resolutions, so upscaling if you want to emulate ROMs may look a bit strange. However, note that the DM42 display is very close to 3x upscaling compared to the HP50g. There would be only a very small number of pixels lost.
2. High-resolution color display: Pros: could take advantage of the color support in DB50x. Can be seen in the dark. See usage of color in HP Prime. Cons: cost, power usage
3. High-resolution color e-ink: Does that even exist? I've seen 6-color displays, but nothing with a high-enough resolution. Did not look in a long time.
4.

xavierbasc, 2025-01-24:
I was considering different types of screens, including e-ink displays, but the issue with them is that there are no screens of a similar size (65-70mm) with the connector (especially this one) located at the top or bottom. All the ones I found (and I searched a lot) had the connector on the side, which adds unused space to the side of the calculator, making it look frankly bad.

I also want to thank c3d for the helpful comments and insights.

RamKromberg, 2025-03-04:
For reference, the [LS027B7DH01](https://www.sharpsde.com/products/displays/model/LS027B7DH01/) that's being used in [similar projects](https://github.com/apoluekt/OpenRPNCalc/) is 58.80mm W x 35.28mm H (=68.58mm=2.7inch diagonal) and there were indeed some users saying it's a bit too small for their liking.

Anyhow, I looked up "FSTN positive monochrome" and found this one from SEACOMP's Displaytech can be specified without a backlight: https://www.seacomp.com/product/graphic-lcd-display-128240c

I figured where there's one there's more and indeed this one from SCCdisplay also seems to fit the bill: https://www.alibaba.com/product-detail/Hot-sale-high-quality-NO-Backlight_1600737771015.html

But with both cases I'm not sure whether not having a backlight means it's clear enough to run without a backlight or that you're supposed to supply one yourself... Either way, SCCdisplay can me reached through their aliexpress store where they sell individual units if anyone wants to pursue this: https://www.aliexpress.com/store/1102309948

So, there might be alternatives.

xavierbasc, 2025-03-04:
Thanks for the feedback. The truth is that this project is still in its
early stages and is more of a personal experiment. Choosing the display was
a real headache, and I considered everything you mentioned. I’m familiar
with the resolution of the HP50 you referenced, but the goal isn’t to run
existing software as-is. Rather, it’s about developing something entirely
new—perhaps leveraging some existing calculation engines, but not
everything, including the display and emulators as they currently exist.

In fact, I’ve been working for some time on a significant hardware redesign
to incorporate high-resolution audio and a style similar to the Pocket
Operator—something that doesn’t require printing anything but still looks
elegant. Each button would have an LED and an audio jack. At the same time,
I want to allow users to save on assembly costs by making features like
lighting and sound optional. Ideally, users could order the PCB from a
manufacturer like PCBWay, and it would arrive almost fully assembled.

I won’t bore you with all the details about displays, but it really was a
major challenge. I have numerous spreadsheets comparing them, and I’ve
analyzed nearly everything on the market. Just to give you a quick
overview: the Sharp display from the DM40, for example, would significantly
increase the base price of the calculator, and I wanted something simple
but affordable. On the other hand, e-ink displays have a major drawback for
me—the thick side margins without usable screen space. This makes the
overall design of the calculator look bad. I’ve searched extensively for
60–70mm screens without those margins or with them only at the top and
bottom, but in the end, I gave up. If you happen to find one, I’d really
appreciate it.

I’m glad to read your thoughts, and if you’d like to collaborate, I’d be
happy to have you on board, though I don’t spend too much time on this
project.

El El dom, 5 ene 2025 a las 15:18, Christophe de Dinechin <
***@***.***> escribió:

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

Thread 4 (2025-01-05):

Add newRPL as possible firmware base

c3d, 2025-01-05:
You list some "software" as opposed to firmware.

newRPL is missing from the list. And it is also a complete firmware for the HP50g.

BTW, any suggestion regarding the base OS? I think HP calculators have used FreeRTOS for a while.

xavierbasc, 2025-01-24:
It won’t really have an operating system as such, but rather an interface with the hardware, with the main hardware management functions shared in a core—something similar to the DMCP from SwissMicros. I recommend checking out the following article I wrote on the project’s website, which outlines the main ideas: [https://50calc.com/heart-dm50/](https://50calc.com/heart-dm50/).

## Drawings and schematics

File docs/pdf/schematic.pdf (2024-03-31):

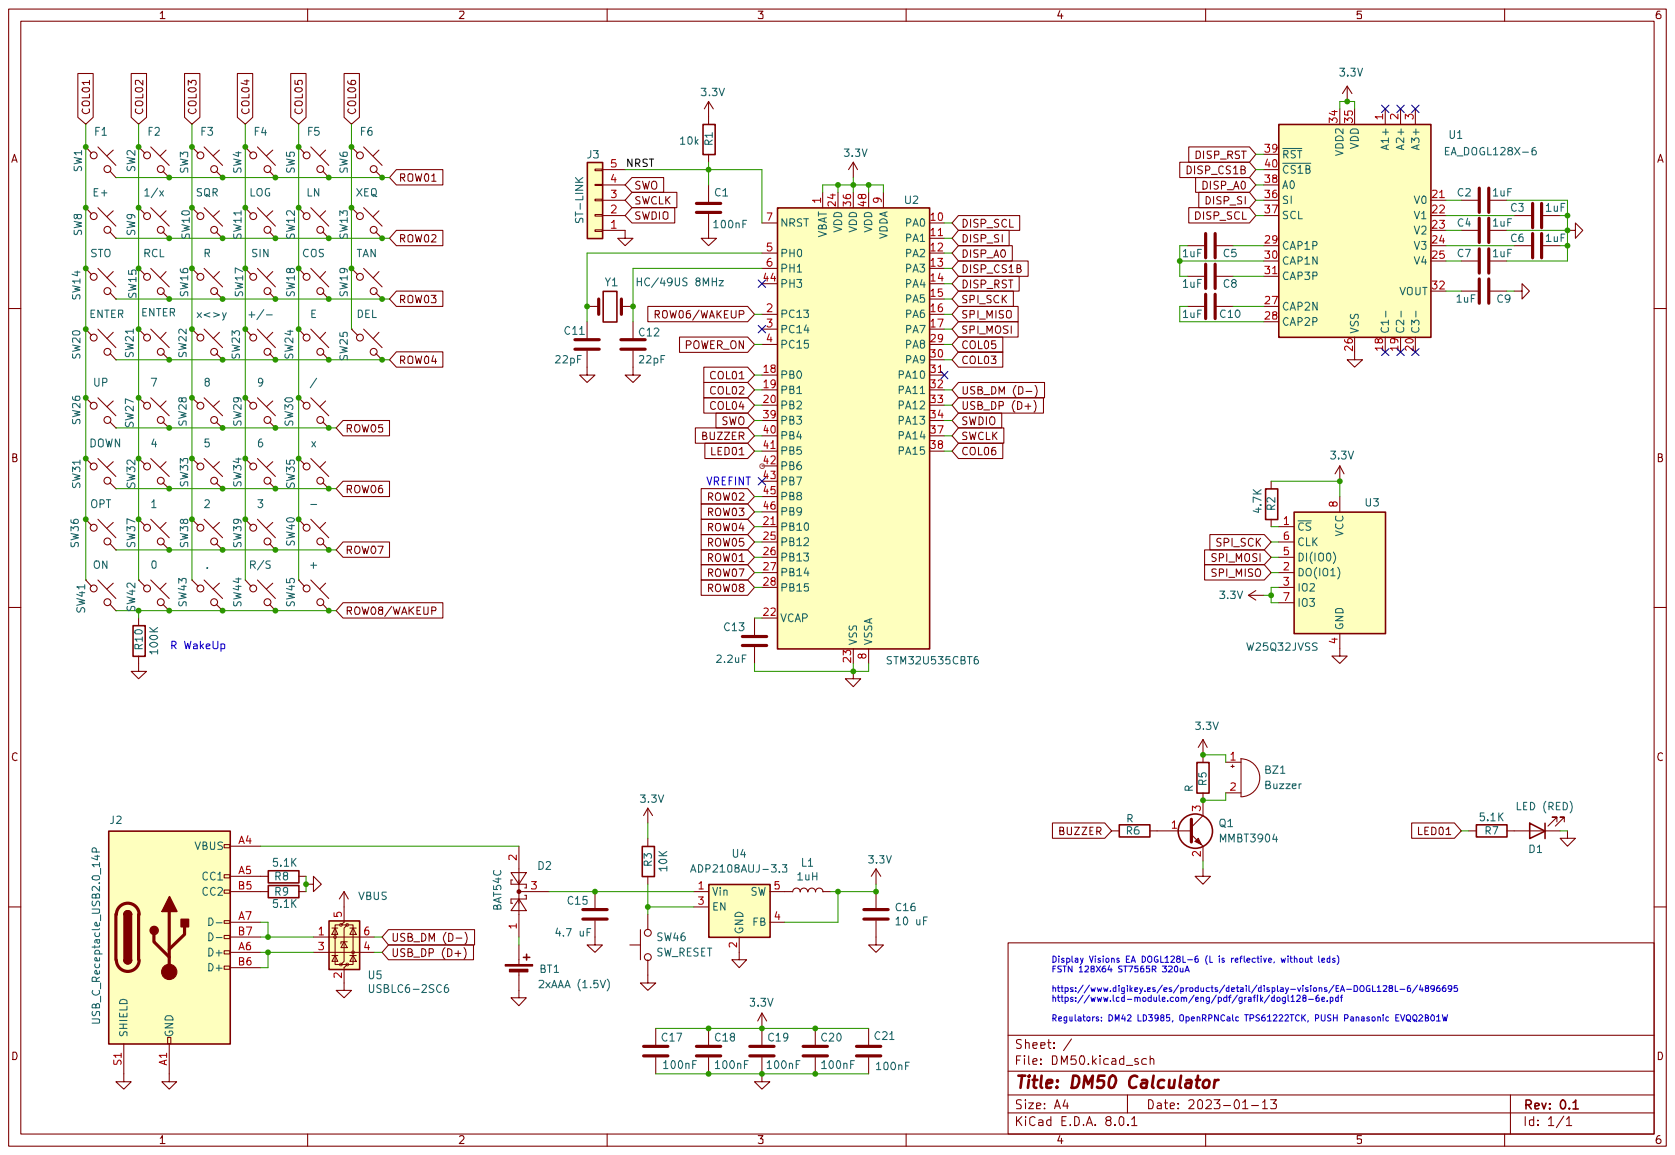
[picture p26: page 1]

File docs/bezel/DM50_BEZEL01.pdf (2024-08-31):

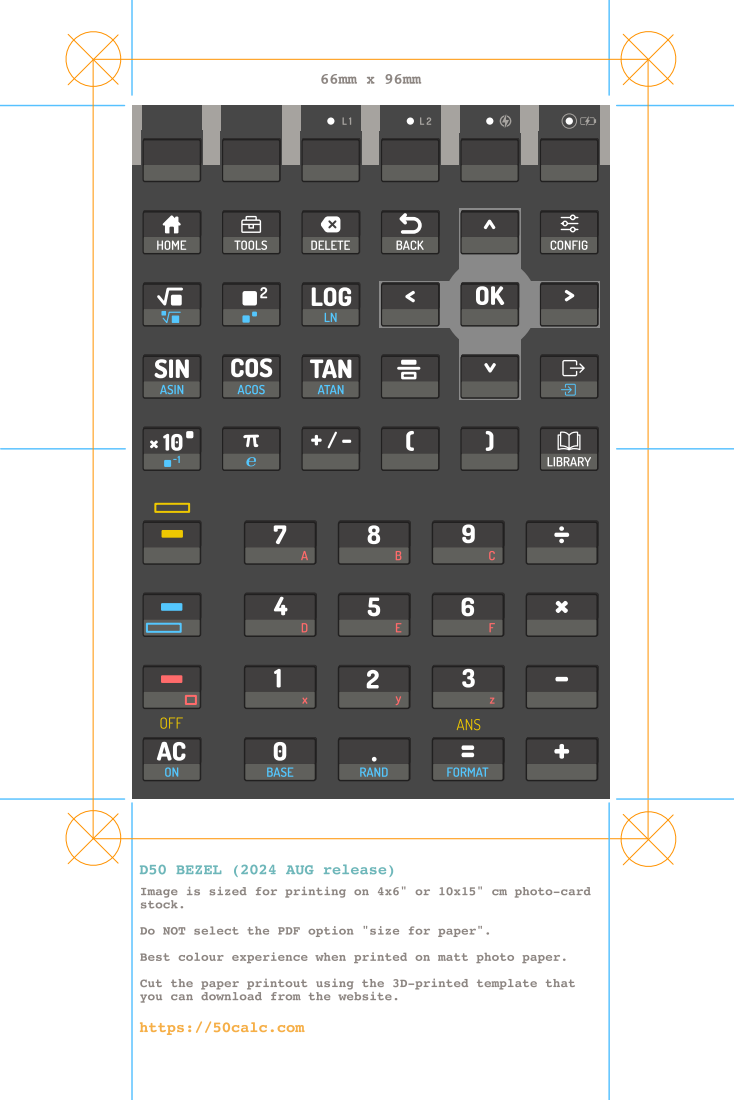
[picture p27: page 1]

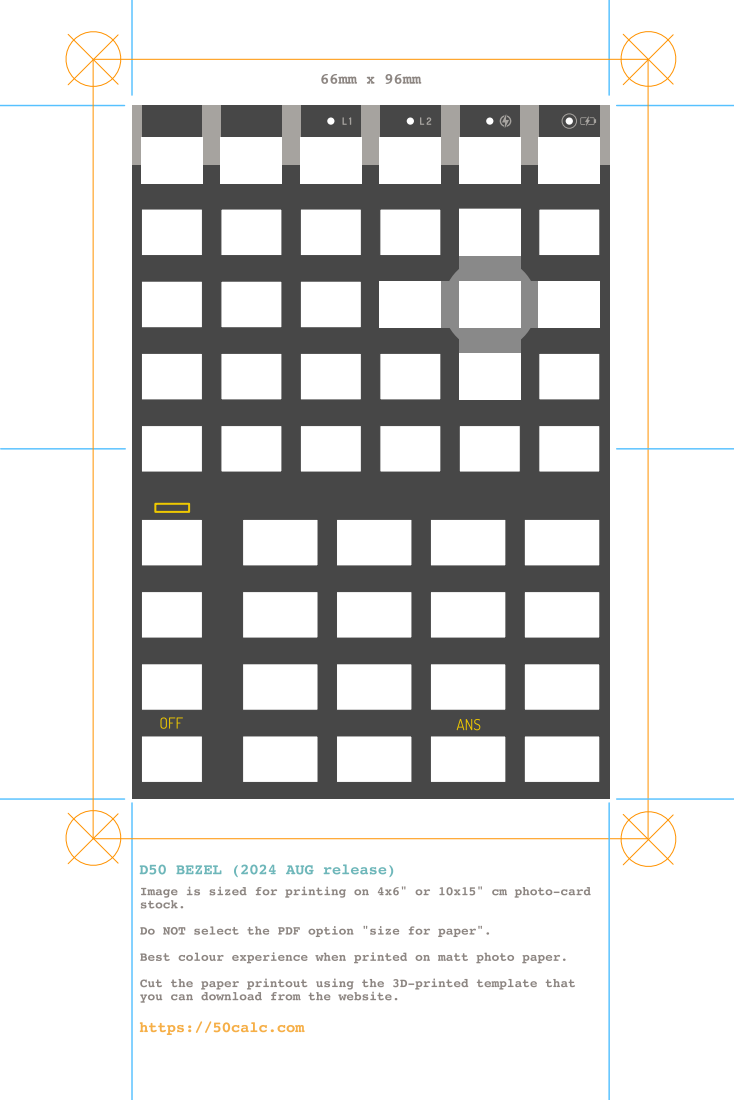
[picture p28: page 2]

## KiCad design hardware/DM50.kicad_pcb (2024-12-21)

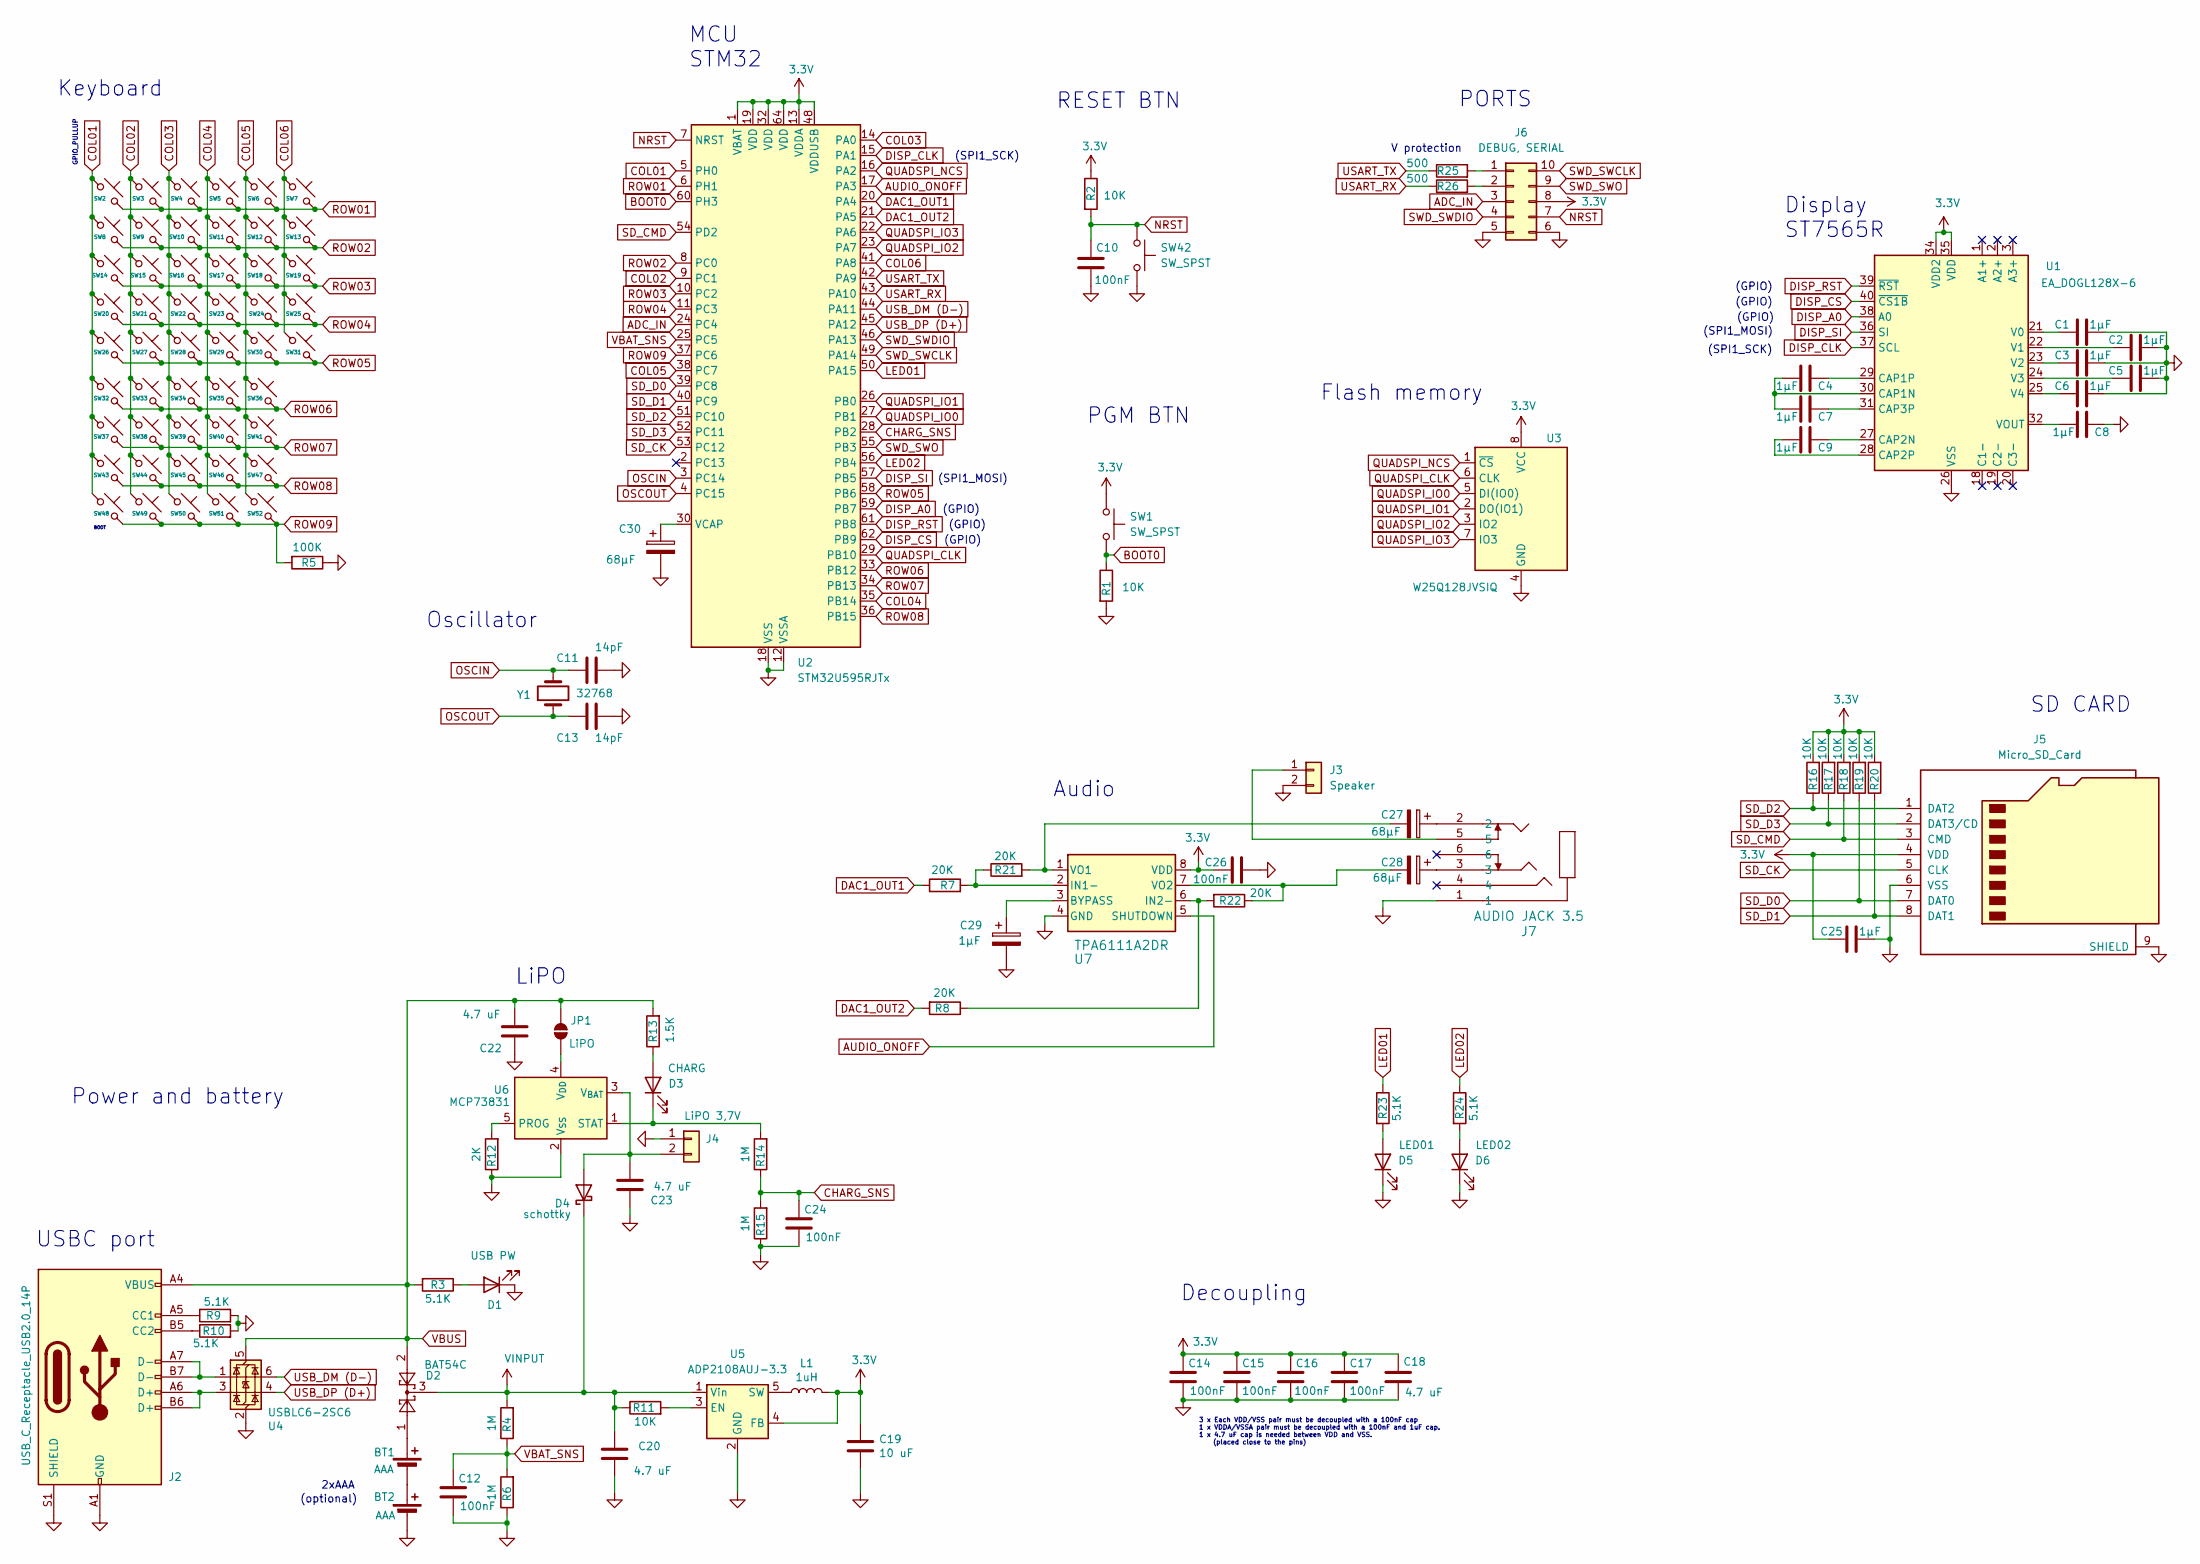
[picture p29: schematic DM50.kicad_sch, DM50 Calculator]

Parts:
BT1, BT2: AAA; dm50-batAAA; Digikey BK-82 (x4)
C1, C2, C3, C4, C5, C6, C7, C8, C9, C25, C29: 1µF; C_0603_1608Metric; Digikey CC0603KRX7R7BB105
C10, C12, C14, C15, C16, C17, C24, C26: 100nF; C_0603_1608Metric; Digikey CC0603KRX7R7BB104
C11, C13: 14pF; C_0603_1608Metric; Digikey CL10C060DB8NNNC
C18, C20, C22, C23: 4.7 uF; C_0603_1608Metric; Digikey CL10A475KP8NNNC
C19: 10 uF; C_0603_1608Metric; Digikey LMK107BBJ106MALT
C27, C28, C30: 68µF; C_1210_3225Metric; Digikey C3216X5R0J686M160AB
D1: USB PW; LED_0603_1608Metric; Digikey LTST-C190GKT
D2: BAT54C; SOT-23; Digikey BAT54C
D3: CHARG; LED_0603_1608Metric; Digikey LTST-S270KRKT
D4: schottky; D_SOD-323; Digikey 1PS76SB10,115
D5: LED01; LED_0603_1608Metric; Digikey LTST-S270KRKT
D6: LED02; LED_0603_1608Metric; Digikey LTST-S270KRKT
J2: USB_C_Receptacle_USB2.0_14P; USB_C_Receptacle_GCT_USB4105-xx-A_16P_TopMnt_Horizontal; Digikey 12402012E212A
J3: Speaker; Buzzer; Digikey CMS-15113-078L100
J4: LiPO 3,7V; CONN_S2B-PH-K-S_JST; Digikey S2B-PH-K-S
J5: Micro_SD_Card; 502570-0893_MOL; Digikey DM3AT-SF-PEJM5
J6: DEBUG, SERIAL; 610110249221; Digikey 610110249221
J7: AUDIO JACK 3.5; SJ-43516-SMT_CUD; Digikey SJ-43516-SMT-TR
JP1: LiPO; SolderJumper-2_P1.3mm_Bridged_RoundedPad1.0x1.5mm
L1: 1uH; L_0805_2012Metric_Pad1.15x1.40mm_HandSolder; Digikey MLZ1608A1R0WT000
R1, R2, R11, R16, R17, R18, R19, R20: 10K; R_0603_1608Metric; Digikey RMCF0603JT10K0
R3, R9, R10, R23, R24: 5.1K; R_0603_1608Metric; Digikey RC0603FR-075K1L
R4, R6, R14, R15: 1M; R_0603_1608Metric; Digikey RMCF0603FT1M00
R5: 100K; R_0603_1608Metric; Digikey RC0603FR-07100KL
R7, R8, R21, R22: 20K; R_0603_1608Metric; Digikey RMCF0603JT10K0
R12: 2K; R_0603_1608Metric; Digikey ERJ-3EKF2001V
R13: 1.5K; R_0603_1608Metric; Digikey RC0603JR-071K5L
R25, R26: 500; R_0603_1608Metric; Digikey RMCF0603JT10K0
SW1, SW42: SW_SPST; SW_SPST_CK_KMS2xxG; Digikey KMS223GPLFG
SW2, SW3, SW4, SW5, SW6, SW7, SW8, SW9, SW10, SW11, SW12, SW13, SW14, SW15, SW16, SW17, SW18, SW19, SW20, SW21, SW22, SW23, SW24, SW25, SW26, SW27, SW28, SW29, SW30, SW31, SW32, SW33, SW34, SW35, SW36, SW37, SW38, SW39, SW40, SW41, SW43, SW44, SW45, SW46, SW47, SW48, SW49, SW50, SW51, SW52: BT_SMD; dm50-button; Digikey dome 7.0mm, three dimple
U1: EA_DOGL128X-6; EA DOGL128L-6; Digikey EA DOGL128L-6
U2: STM32U595RJTx; LQFP-64_10x10mm_P0.5mm; Digikey STM32U595RJTx
U3: W25Q128JVSIQ; SOIC-8_3.9x4.9mm_P1.27mm; Digikey W25Q128JVSIQ
U4: USBLC6-2SC6; SOT-23-6; Digikey USBLC6-2SC6
U5: ADP2108AUJ-3.3; TSOT-23-5; Digikey ADP2108AUJZ-3.3-R7
U6: MCP73831; SOT-23-5; Digikey MCP73831T-2ACI/OT
U7: TPA6111A2DR; SOIC-8-1EP_3.9x4.9mm_P1.27mm_EP2.41x3.81mm_ThermalVias; Digikey TPA6111A2DR
Y1: 32768; XTAL_ABS05-32.768KHZ-9-T

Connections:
3.3V: C14.1, C15.1, C16.1, C17.1, C18.1, C19.1, C25.1, C26.1, J5.4 (VDD), J6.8, L1.2, R2.1, R16.2, R17.2, R18.2, R19.2, R20.2, SW1.1, U1.34 (VDD2), U1.35 (VDD), U2.1 (VBAT), U2.13 (VDDA), U2.19 (VDD), U2.32 (VDD), U2.48 (VDDUSB), U2.64 (VDD), U3.8 (VCC), U5.4 (FB), U7.8 (VDD)
ADC_IN: J6.3, U2.24 (PC4)
AUDIO_ONOFF: U2.17 (PA3), U7.5 (SHUTDOWN)
BOOT0: R1.1, SW1.2, U2.60 (PH3)
CHARG_SNS: C24.1, R14.1, R15.2, U2.28 (PB2)
COL01: SW2.1, SW8.1, SW14.1, SW20.1, SW26.1, SW32.1, SW37.1, SW43.1, SW48.1, U2.5 (PH0)
COL02: SW3.1, SW9.1, SW15.1, SW21.1, SW27.1, SW33.1, SW38.1, SW44.1, SW49.1, U2.9 (PC1)
COL03: SW4.1, SW10.1, SW16.1, SW22.1, SW28.1, SW34.1, SW39.1, SW45.1, SW50.1, U2.14 (PA0)
COL04: SW5.1, SW11.1, SW17.1, SW23.1, SW29.1, SW35.1, SW40.1, SW46.1, SW51.1, U2.35 (PB14)
COL05: SW6.1, SW12.1, SW18.1, SW24.1, SW30.1, SW36.1, SW41.1, SW47.1, SW52.1, U2.38 (PC7)
COL06: SW7.1, SW13.1, SW19.1, SW25.1, SW31.1, U2.41 (PA8)
DAC1_OUT1: R7.1, U2.20 (PA4)
DAC1_OUT2: R8.2, U2.21 (PA5)
DISP_A0: U1.38 (A0), U2.59 (PB7)
DISP_CLK: U1.37 (SCL), U2.15 (PA1)
DISP_CS: U1.40 (~CS1B), U2.62 (PB9)
DISP_RST: U1.39 (~RST), U2.61 (PB8)
DISP_SI: U1.36 (SI), U2.57 (PB5)
GND: BT2.2 (-), C1.2, C2.2, C3.2, C5.2, C6.2, C8.1, C10.2, C11.2, C12.2, C13.2, C14.2, C15.2, C16.2, C17.2, C18.2, C19.2, C20.2, C22.1, C23.2, C24.2, C25.2, C26.2, C29.2, C30.2, D1.1 (K), D5.1 (K), D6.1 (K), J2.A1 (GND), J2.A12 (GND), J2.B1 (GND), J2.B12 (GND), J2.S1 (SHIELD), J3.2, J4.1, J5.6 (VSS), J5.9 (SHIELD), J6.5, J6.6, J7.1, R1.2, R5.1, R6.1, R9.2, R10.2, R12.1, R15.1, SW42.2, U1.26 (VSS), U1.33 (VSS), U2.12 (VSSA), U2.18 (VSS), U2.31 (VSS), U2.47 (VSS), U2.63 (VSS), U3.4 (GND), U4.2 (GND), U5.2 (GND), U6.2 (V_{SS}), U7.4 (GND)
LED01: R23.1, U2.50 (PA15)
LED02: R24.1, U2.56 (PB4)
NRST: C10.1, J6.7, R2.2, SW42.1, U2.7 (NRST)
unnamed: BT1.1 (+), D2.1
unnamed: BT1.2 (-), BT2.1 (+)
unnamed: C27.1, J7.2
unnamed: C28.1, J7.3
unnamed: D1.2 (A), R3.1
unnamed: D3.2 (A), R13.1
unnamed: D3.1 (K), R14.2, U6.1 (STAT)
unnamed: C23.1, D4.2 (A), J4.2, U6.3 (V_{BAT})
unnamed: D5.2 (A), R23.2
unnamed: D6.2 (A), R24.2
unnamed: J2.A5 (CC1), R9.1
unnamed: J2.B5 (CC2), R10.1
unnamed: J2.A6 (D+), J2.B6 (D+), U4.3 (I/O2)
unnamed: J2.A7 (D-), J2.B7 (D-), U4.1 (I/O1)
unnamed: J3.1, J7.5
unnamed: J6.1, R25.2
unnamed: J6.2, R26.2
unnamed: JP1.1 (A), U6.4 (V_{DD})
unnamed: C4.2, C7.2, U1.30 (CAP1N)
unnamed: C4.1, U1.29 (CAP1P)
unnamed: C9.1, U1.27 (CAP2N)
unnamed: C9.2, U1.28 (CAP2P)
unnamed: C7.1, U1.31 (CAP3P)
unnamed: C1.1, U1.21 (V0)
unnamed: C2.1, U1.22 (V1)
unnamed: C3.1, U1.23 (V2)
unnamed: C5.1, U1.24 (V3)
unnamed: C6.1, U1.25 (V4)
unnamed: C8.2, U1.32 (VOUT)
unnamed: C30.1, U2.30 (VCAP)
unnamed: R11.2, U5.3 (EN)
unnamed: L1.1, U5.5 (SW)
unnamed: R12.2, U6.5 (PROG)
unnamed: C29.1, U7.3 (BYPASS)
unnamed: R7.2, R21.1, U7.2 (IN1-)
unnamed: R8.1, R22.2, U7.6 (IN2-)
unnamed: C27.2, R21.2, U7.1 (VO1)
unnamed: C28.2, R22.1, U7.7 (VO2)
OSCIN: C11.1, U2.3 (PC14), Y1.2
OSCOUT: C13.1, U2.4 (PC15), Y1.1
QUADSPI_CLK: U2.29 (PB10), U3.6 (CLK)
QUADSPI_IO0: U2.27 (PB1), U3.5 (DI(IO0))
QUADSPI_IO1: U2.26 (PB0), U3.2 (DO(IO1))
QUADSPI_IO2: U2.23 (PA7), U3.3 (IO2)
QUADSPI_IO3: U2.22 (PA6), U3.7 (IO3)
QUADSPI_NCS: U2.16 (PA2), U3.1 (~CS)
ROW01: SW2.2, SW3.2, SW4.2, SW5.2, SW6.2, SW7.2, U2.6 (PH1)
ROW02: SW8.2, SW9.2, SW10.2, SW11.2, SW12.2, SW13.2, U2.8 (PC0)
ROW03: SW14.2, SW15.2, SW16.2, SW17.2, SW18.2, SW19.2, U2.10 (PC2)
ROW04: SW20.2, SW21.2, SW22.2, SW23.2, SW24.2, SW25.2, U2.11 (PC3)
ROW05: SW26.2, SW27.2, SW28.2, SW29.2, SW30.2, SW31.2, U2.58 (PB6)
ROW06: SW32.2, SW33.2, SW34.2, SW35.2, SW36.2, U2.33 (PB12)
ROW07: SW37.2, SW38.2, SW39.2, SW40.2, SW41.2, U2.34 (PB13)
ROW08: SW43.2, SW44.2, SW45.2, SW46.2, SW47.2, U2.36 (PB15)
ROW09: R5.2, SW48.2, SW49.2, SW50.2, SW51.2, SW52.2, U2.37 (PC6)
SD_CK: J5.5 (CLK), U2.53 (PC12)
SD_CMD: J5.3 (CMD), R18.1, U2.54 (PD2)
SD_D0: J5.7 (DAT0), R19.1, U2.39 (PC8)
SD_D1: J5.8 (DAT1), R20.1, U2.40 (PC9)
SD_D2: J5.1 (DAT2), R16.1, U2.51 (PC10)
SD_D3: J5.2 (DAT3/CD), R17.1, U2.52 (PC11)
SWD_SWCLK: J6.10, U2.49 (PA14)
SWD_SWDIO: J6.4, U2.46 (PA13)
SWD_SWO: J6.9, U2.55 (PB3)
USART_RX: R26.1, U2.43 (PA10)
USART_TX: R25.1, U2.42 (PA9)
USB_DM (D-): U2.44 (PA11), U4.6 (I/O1)
USB_DP (D+): U2.45 (PA12), U4.4 (I/O2)
VBAT_SNS: C12.1, R4.1, R6.2, U2.25 (PC5)
VBUS: C22.2, D2.2, J2.A4 (VBUS), J2.A9 (VBUS), J2.B4 (VBUS), J2.B9 (VBUS), JP1.2 (B), R3.2, R13.2, U4.5 (VBUS)
VINPUT: C20.1, D2.3, D4.1 (K), R4.2, R11.1, U5.1 (Vin)

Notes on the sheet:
(GPIO)
Oscillator
(optional)
Decoupling
(SPI1_MOSI)
PORTS
Power and battery
MCU STM32
USBC port
V protection
Keyboard
GPIO_PULLUP
Flash memory
2xAAA
LiPO
Display ST7565R
(SPI1_SCK)
PGM BTN
SD CARD
RESET BTN
3 x Each VDD/VSS pair must be decoupled with a 100nF cap 1 x VDDA/VSSA pair must be decoupled with a 100nF and 1uF cap. 1 x 4.7 uF cap is needed between VDD and VSS. (placed close to the pins)
Audio
BOOT

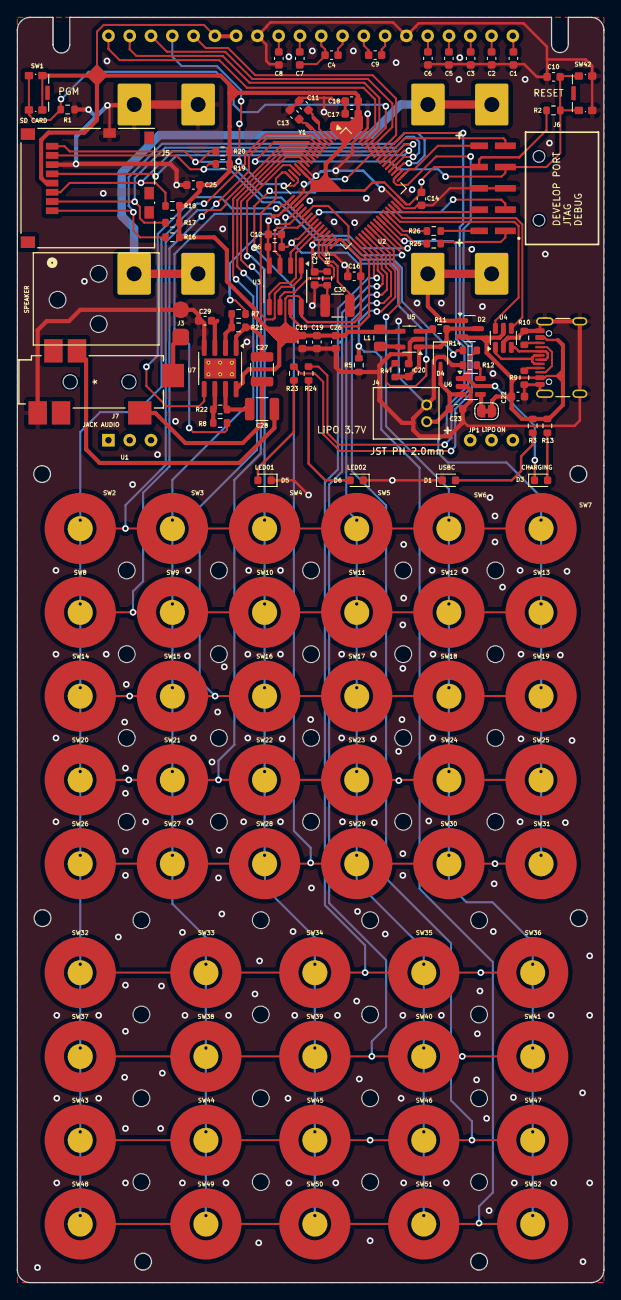
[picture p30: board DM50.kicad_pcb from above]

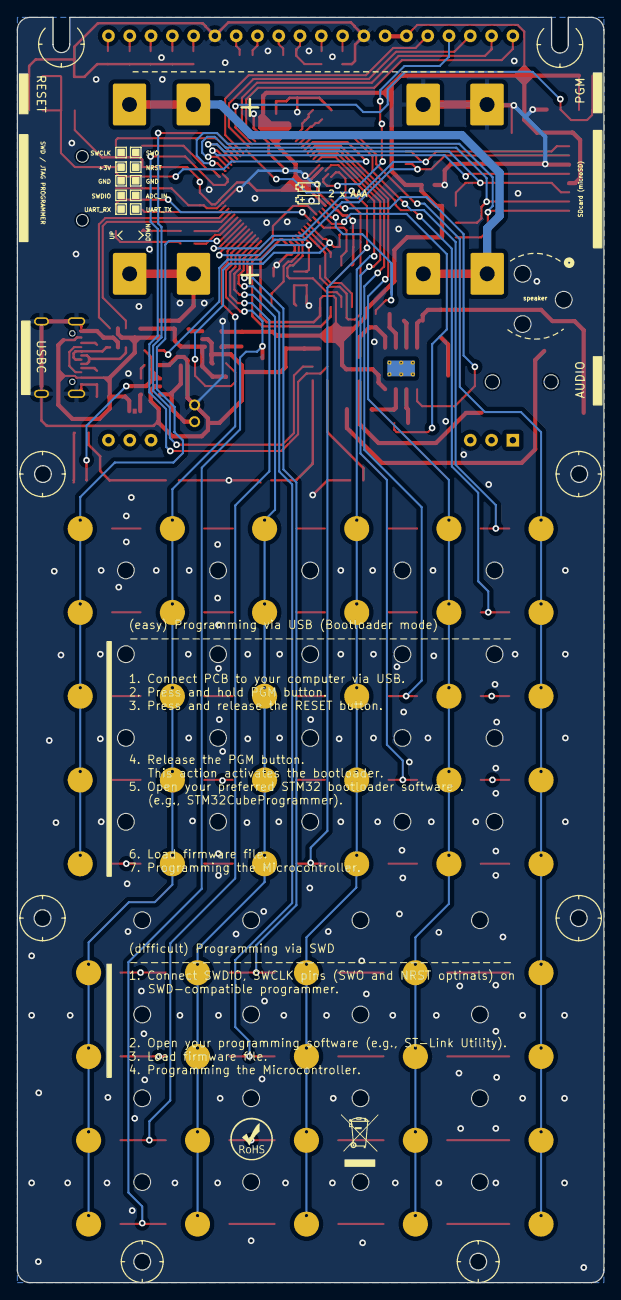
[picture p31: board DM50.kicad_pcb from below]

Board: 2 copper layers, 70.0 x 151.0 mm, 131 parts (2 on the bottom side), 93 nets.

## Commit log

2023-01-07 initial file creation
    [DM50.kicad_pcb, DM50.kicad_sch]
2023-01-12 Paths changes
    [DM50.kicad_pcb, DM50.kicad_sch]
2023-01-13 SCH changes
    [DM50.kicad_sch]
2024-03-31 electronic design advances
    [DM50.kicad_pcb, DM50.kicad_sch]
2024-03-31 Global changes
    [DM50.kicad_pcb]
2024-03-31 Shematic changes
    [DM50.kicad_pcb, DM50.kicad_sch]
2024-03-31 structure changes
    [DM50.kicad_pcb, DM50.kicad_sch]
2024-04-02 Schema updates
    [DM50.kicad_sch]
2024-04-03 update 3d render
    [DM50.kicad_pcb, DM50.kicad_sch]
2024-04-03 include PCB image
2024-04-04 3d case init
    [DM50.kicad_pcb, case.scad]
2024-04-04 new image
    [DM50.kicad_pcb]
2024-04-04 pcb changes
    [DM50.kicad_pcb]
2024-04-04 3d case changes
    [DM50.kicad_pcb, case.scad]
2024-04-27 pcb and rendeer
    [DM50.kicad_pcb, DM50.kicad_sch]
2024-05-01 keyboard changes
    [case_1_1.scad]
2024-05-01 3d changes
    [case_1_1.scad, case_1_1.stl]
2024-05-02 3d render
    [case_1_1.scad, case_1_1.stl]
2024-05-03 crystal change
    [DM50.kicad_pcb, DM50.kicad_sch]
2024-05-07 Faceplate init
    [DM50.kicad_pcb]
2024-05-17 case changes
    [DM50.kicad_pcb, case_1_1.scad]
2024-05-25 3d case
    [DM50-B_Cu.gbl, DM50-B_Mask.gbs, DM50-B_Paste.gbp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]
2024-06-30 3d changes (step files)
    [DM50.kicad_pcb, DM50.kicad_sch, EA DOGM128.STEP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]
2024-07-13 LiPO CONNECTOR
    [ABS05-32.768KHZ-9-T.step, DM50.kicad_pcb, DM50.kicad_sch]
2024-07-30 LiPO charging sensor
    [DM50.kicad_pcb, DM50.kicad_sch]
2024-08-01 update schema
    [DM50.kicad_pcb]
2024-08-01 imgs pcb
2024-08-03 housing changes
2024-08-04 remove files
    [base.stl, case.scad, case_1_1.scad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]
2024-08-10 add jtag connector
    [DM50.kicad_pcb, DM50.kicad_sch, SAMTEC-SMH-105-02-X-S.step]
2024-08-10 JTAG connector
    [DM50.kicad_pcb]
2024-08-12 update case image
2024-08-16 STM32U575RIT6 change
    [DM50.kicad_pcb, DM50.kicad_sch]
2024-08-21 pcb updates
    [DM50.kicad_pcb, DM50.kicad_sch]
2024-08-22 pcb upgrades
    [5025700893.step, 610110249221_Download_STP_610110249221_rev1.step, CUI_DEVICES_SJ2-35954D-SMT-TR.step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]
2024-08-23 pcb upgrade
    [DM50.kicad_pcb, DM50.kicad_sch]
2024-08-25 update images
    [DM50.kicad_pcb]
2024-08-26 case upgrade
2024-08-26 bezel changes
    [DM50 components.xlsx]
2024-08-30 case upgrades
    [DM50.kicad_pcb, DM50.kicad_sch]
2024-09-10 texture case
    [case-Cut012.stl, case-Fusion005.stl, case-LEDS.stl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]
2024-09-10 case texture
2024-09-19 case 3d
2024-09-21 3d case
    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
2024-11-09 Added protection resistors against overvoltage on USART ports (thanks to Ruber Aparicio).
    [DM50.kicad_pcb, DM50.kicad_sch]
2024-11-15 LCD port bugfix
    [DM50.kicad_pcb, DM50.kicad_sch]
2024-12-17 3D case V3
    [DM50-B_Cu.gbl, DM50-B_Mask.gbs, DM50-B_Paste.gbp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]
2024-12-21 3d case upgrade
2024-12-27 upgrade 3d detail
    [DM50.kicad_sch]

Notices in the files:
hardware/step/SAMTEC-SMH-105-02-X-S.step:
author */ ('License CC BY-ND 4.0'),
